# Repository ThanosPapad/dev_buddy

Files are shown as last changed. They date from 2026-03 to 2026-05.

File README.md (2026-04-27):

# DevBuddy V1
## An engineer's assistant in development.
*DevBuddy is a project under development aimed to provide engineers with an easy platform to prototype embeeded systems.*

It provides vast options in voltages to be used to supply the target board, current consumption meassurements for all channels, serial communication options and lastly a PC app to monitor and control it.
Should be able to be used for the starting point of any custom testing rig

### File breakdown
* __DevBuddy_mk1__ - _Hardware files in KiCad_.
* __Scripts__ - _Python script for the PC app_.
* __dev_buddy_v1__ - _Firmware for the RP2350 MCU / Device_.
* __Resources__ - _You can find the current PCB schematic PDF and screenshots_.

### Current capabilities
* All communication is happening over UART
* Control digital outputs commanded by the APP
* Reading digital inputs commanded by the APP
* The device is capable of reporting back to the APP measurements of Voltages and Currents of 8 channels, with the ability to switch on or off the function as well as the intervals of the reporting
* The APP looks cool as hell!
* Added support for two 8-Bit DACs for APP and Device
* Added two controllable voltage channels on PCB, firmware will have to come later
* A first version of the dispatcher is operational
* There are three channels of UART communication available to the device and APP

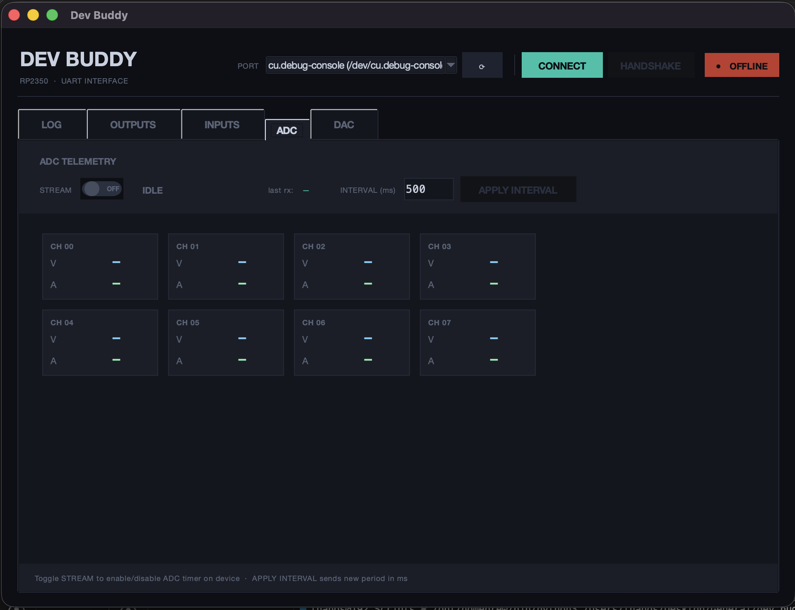
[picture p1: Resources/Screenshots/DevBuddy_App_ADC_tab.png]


There are more screenshots in the folder showcasing the app

### Things that need to be done
* Software (I2C)for the variable voltage channels control
* The ability to record sessions of measuremnts, propably saved as CSV files
* The ability to choose analog channels and view the measurements in a graph would be quite cool as well
* The schematic should progressing quicker
* Need to figure out how the external channels will work, and If external I2C is needed as well
* Add ability for actions from external interrupts, that means one or two pins accessible to the user

More updates to come soon!

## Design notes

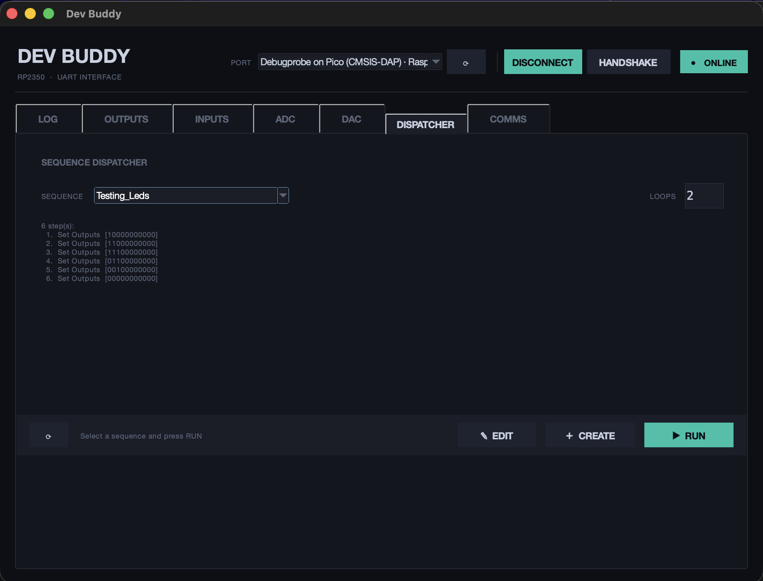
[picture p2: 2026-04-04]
Resources/Screenshots/Dispatcher.png

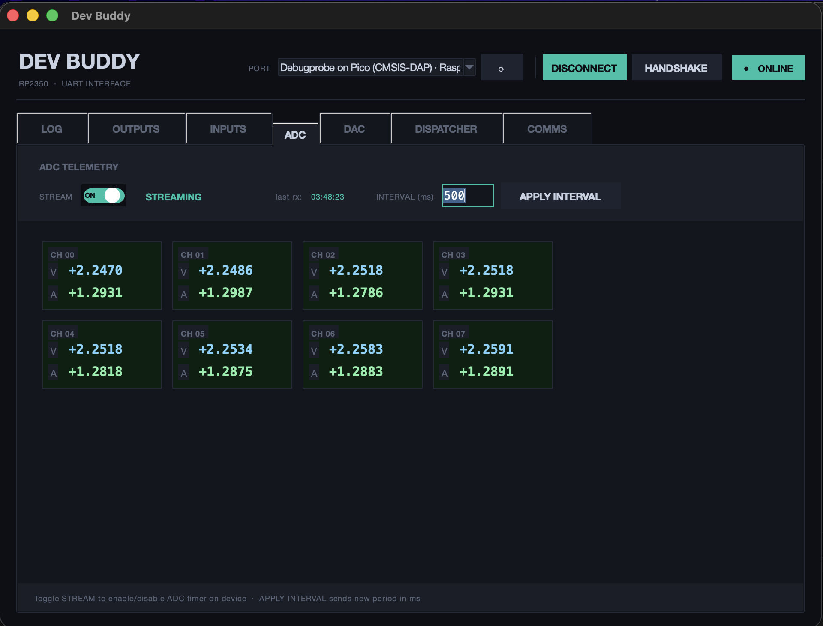
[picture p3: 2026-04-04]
Resources/Screenshots/ADC_Channels_Running.png

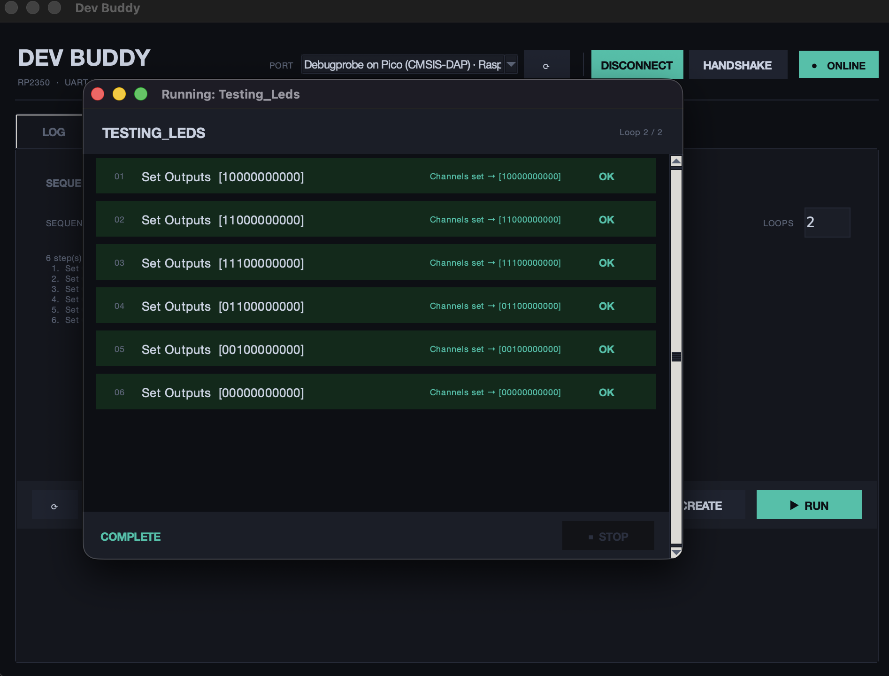
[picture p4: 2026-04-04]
Resources/Screenshots/Dispatcher_runnign.png

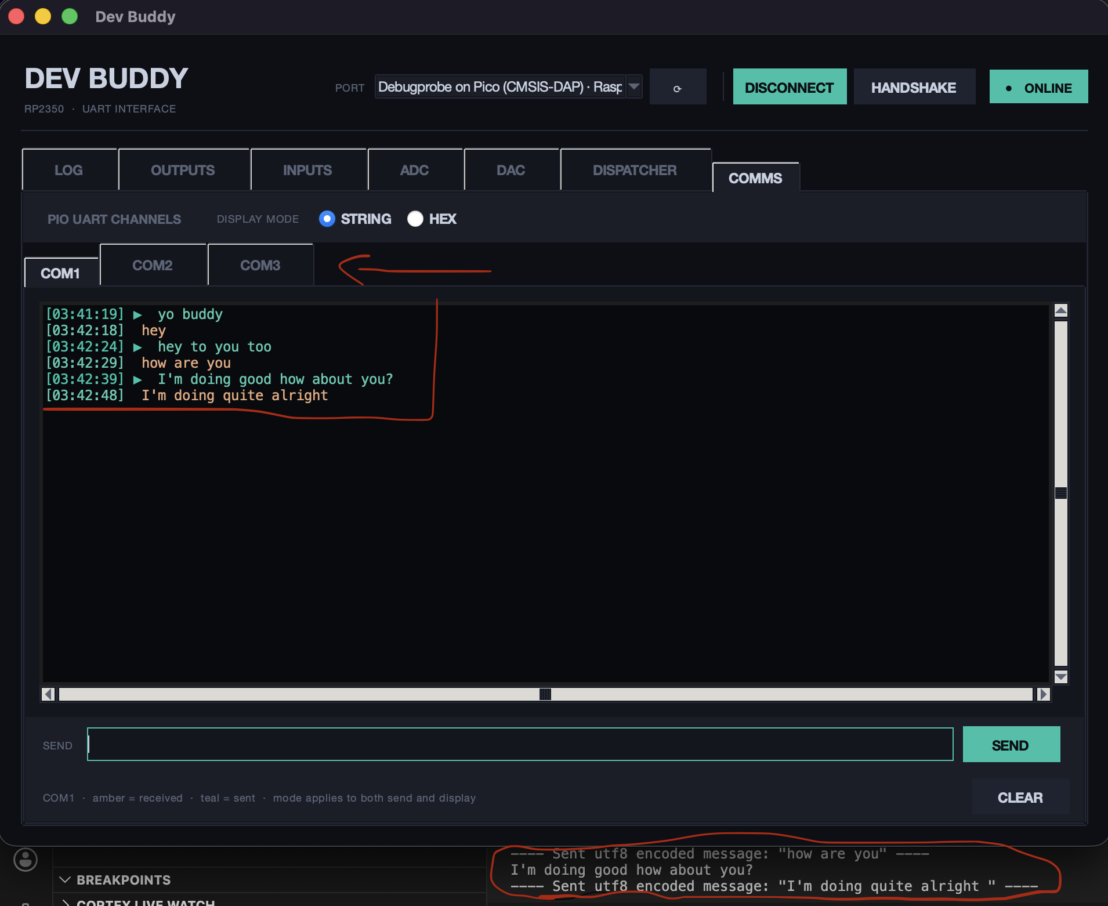
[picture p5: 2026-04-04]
Resources/Screenshots/Uart_Com1_Preview.png

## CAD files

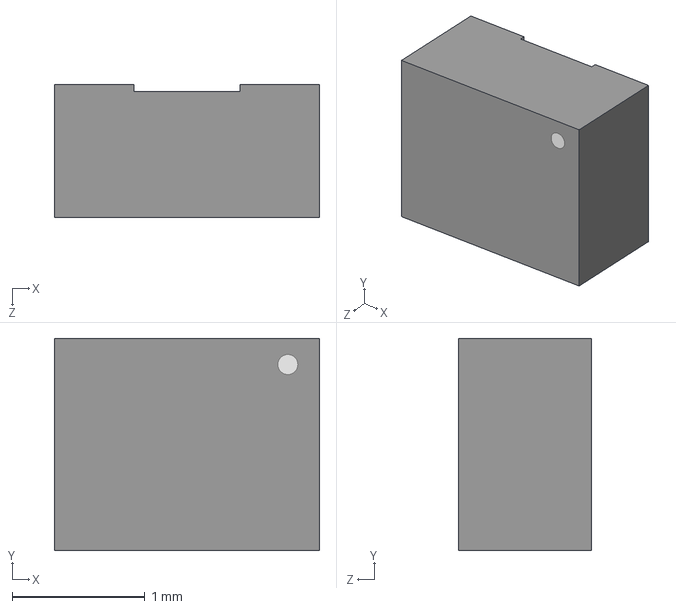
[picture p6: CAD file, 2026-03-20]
DevBuddy_mk1/AOTA-B201610S3R3-101-T/AOTA-B201610S3R3-101-T.stp
2.00 x 1.60 x 1.00 mm

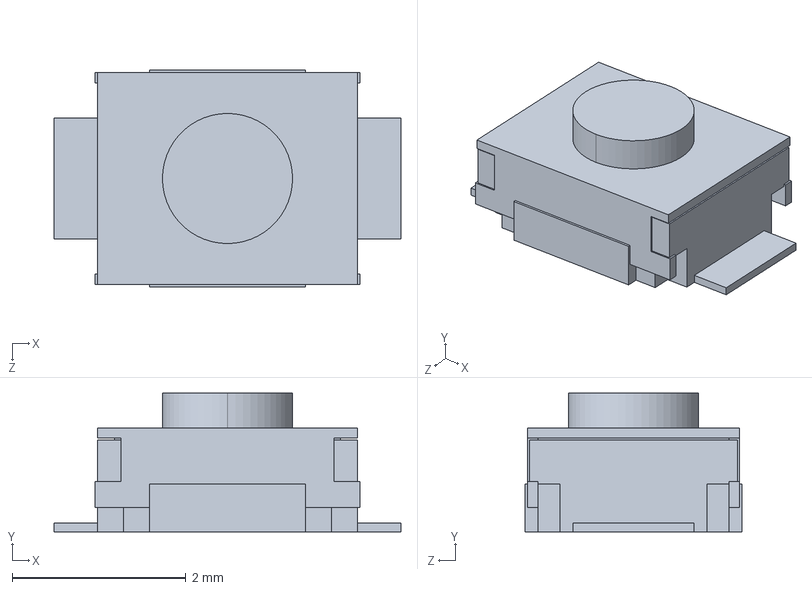
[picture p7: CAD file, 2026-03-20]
DevBuddy_mk1/Button/B3U_1000P.step
4.00 x 1.60 x 2.50 mm

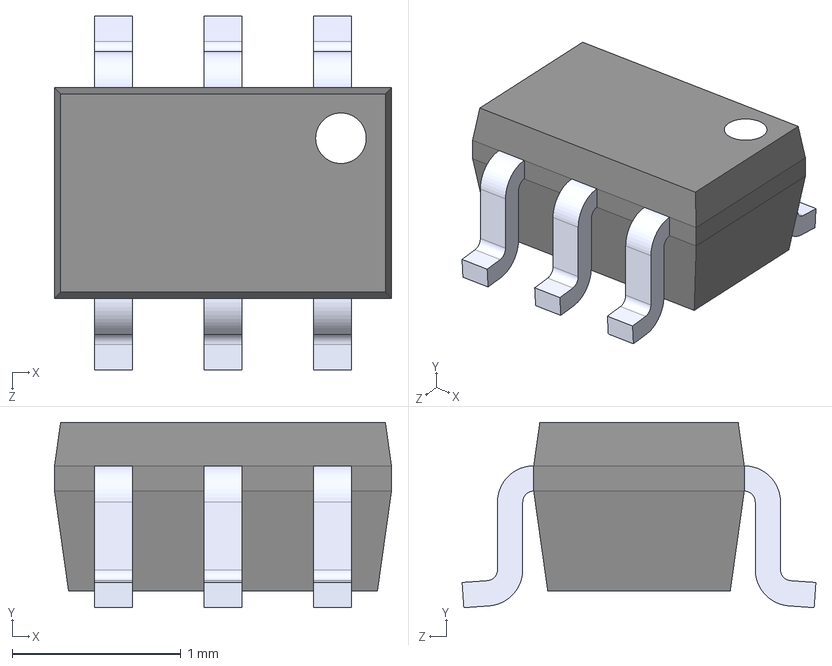
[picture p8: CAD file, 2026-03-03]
DevBuddy_mk1/INA190A2IDCKR/INA190A2IDCKR.step
2.00 x 1.10 x 2.10 mm

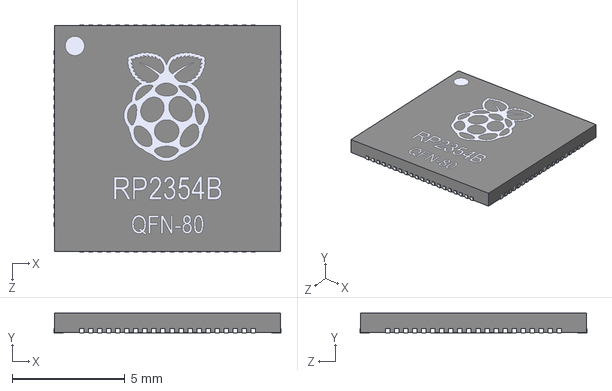
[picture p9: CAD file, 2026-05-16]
DevBuddy_mk1/RP2354B/RP2354B.step
10.1 x 0.875 x 10.1 mm

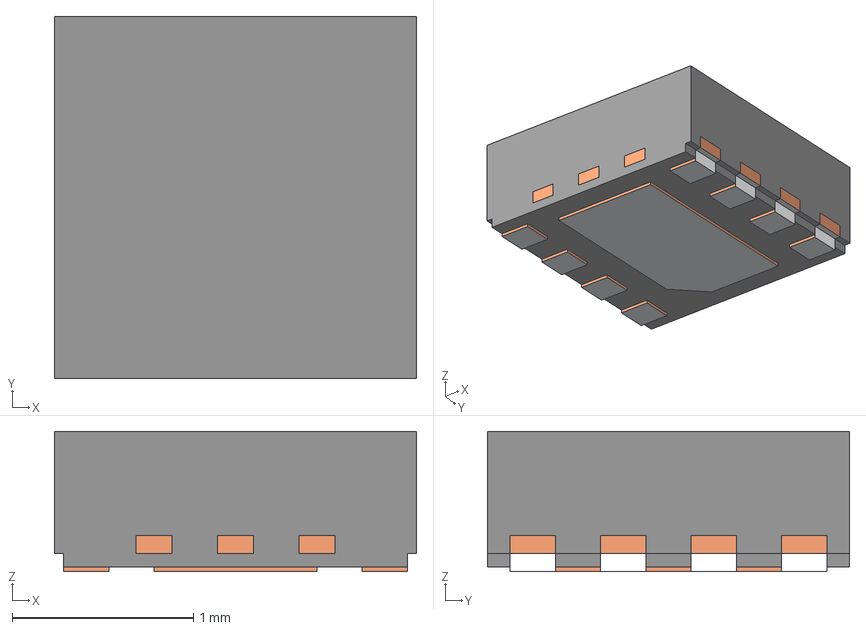
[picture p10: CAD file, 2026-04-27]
DevBuddy_mk1/TPS22965/DSG0008B.stp
2.00 x 2.00 x 0.775 mm
BODY-SON_AF0
FRAME-DSG0008B_AF0
PIN1-ID

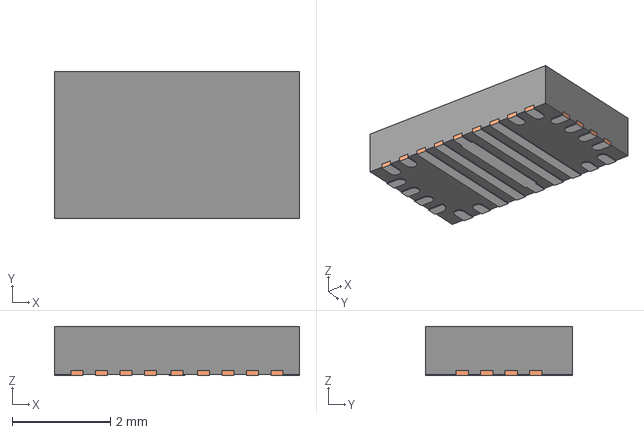
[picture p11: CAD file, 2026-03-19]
DevBuddy_mk1/ul_TPS55289RYQR/KiCADv6/RYQ0021A.stp
5.00 x 3.00 x 1.00 mm
BODY-QFN
FRAME-RYQ0021A

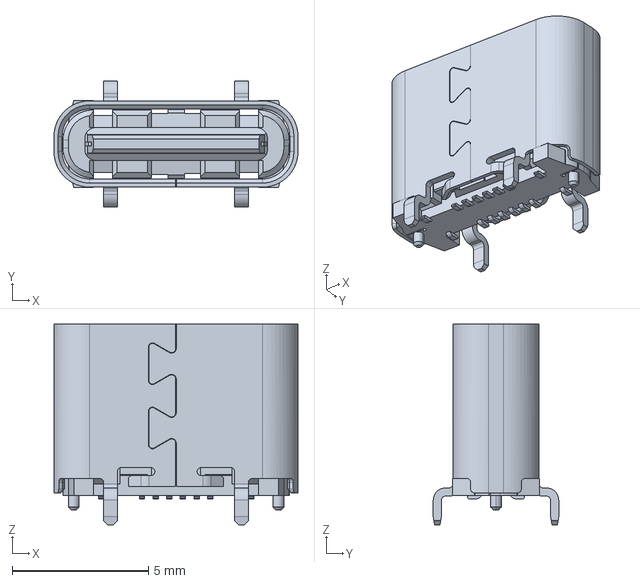
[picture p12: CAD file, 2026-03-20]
DevBuddy_mk1/USB-C-Vertical/2171820001.stp
8.94 x 4.60 x 7.35 mm

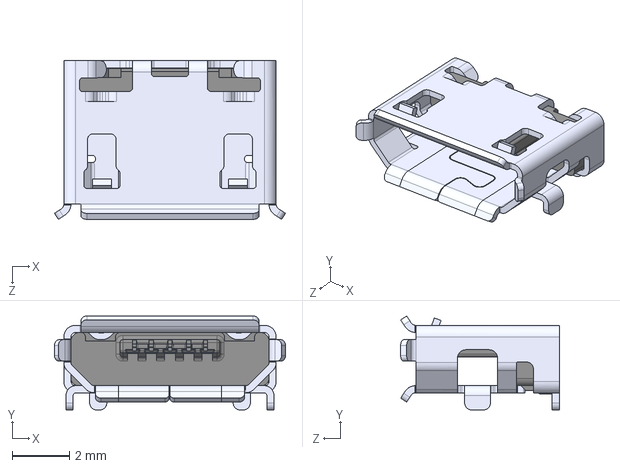
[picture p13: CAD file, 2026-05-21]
DevBuddy_mk1/usb_micro_b/10118194-0001LF.step
8.05 x 3.27 x 5.53 mm

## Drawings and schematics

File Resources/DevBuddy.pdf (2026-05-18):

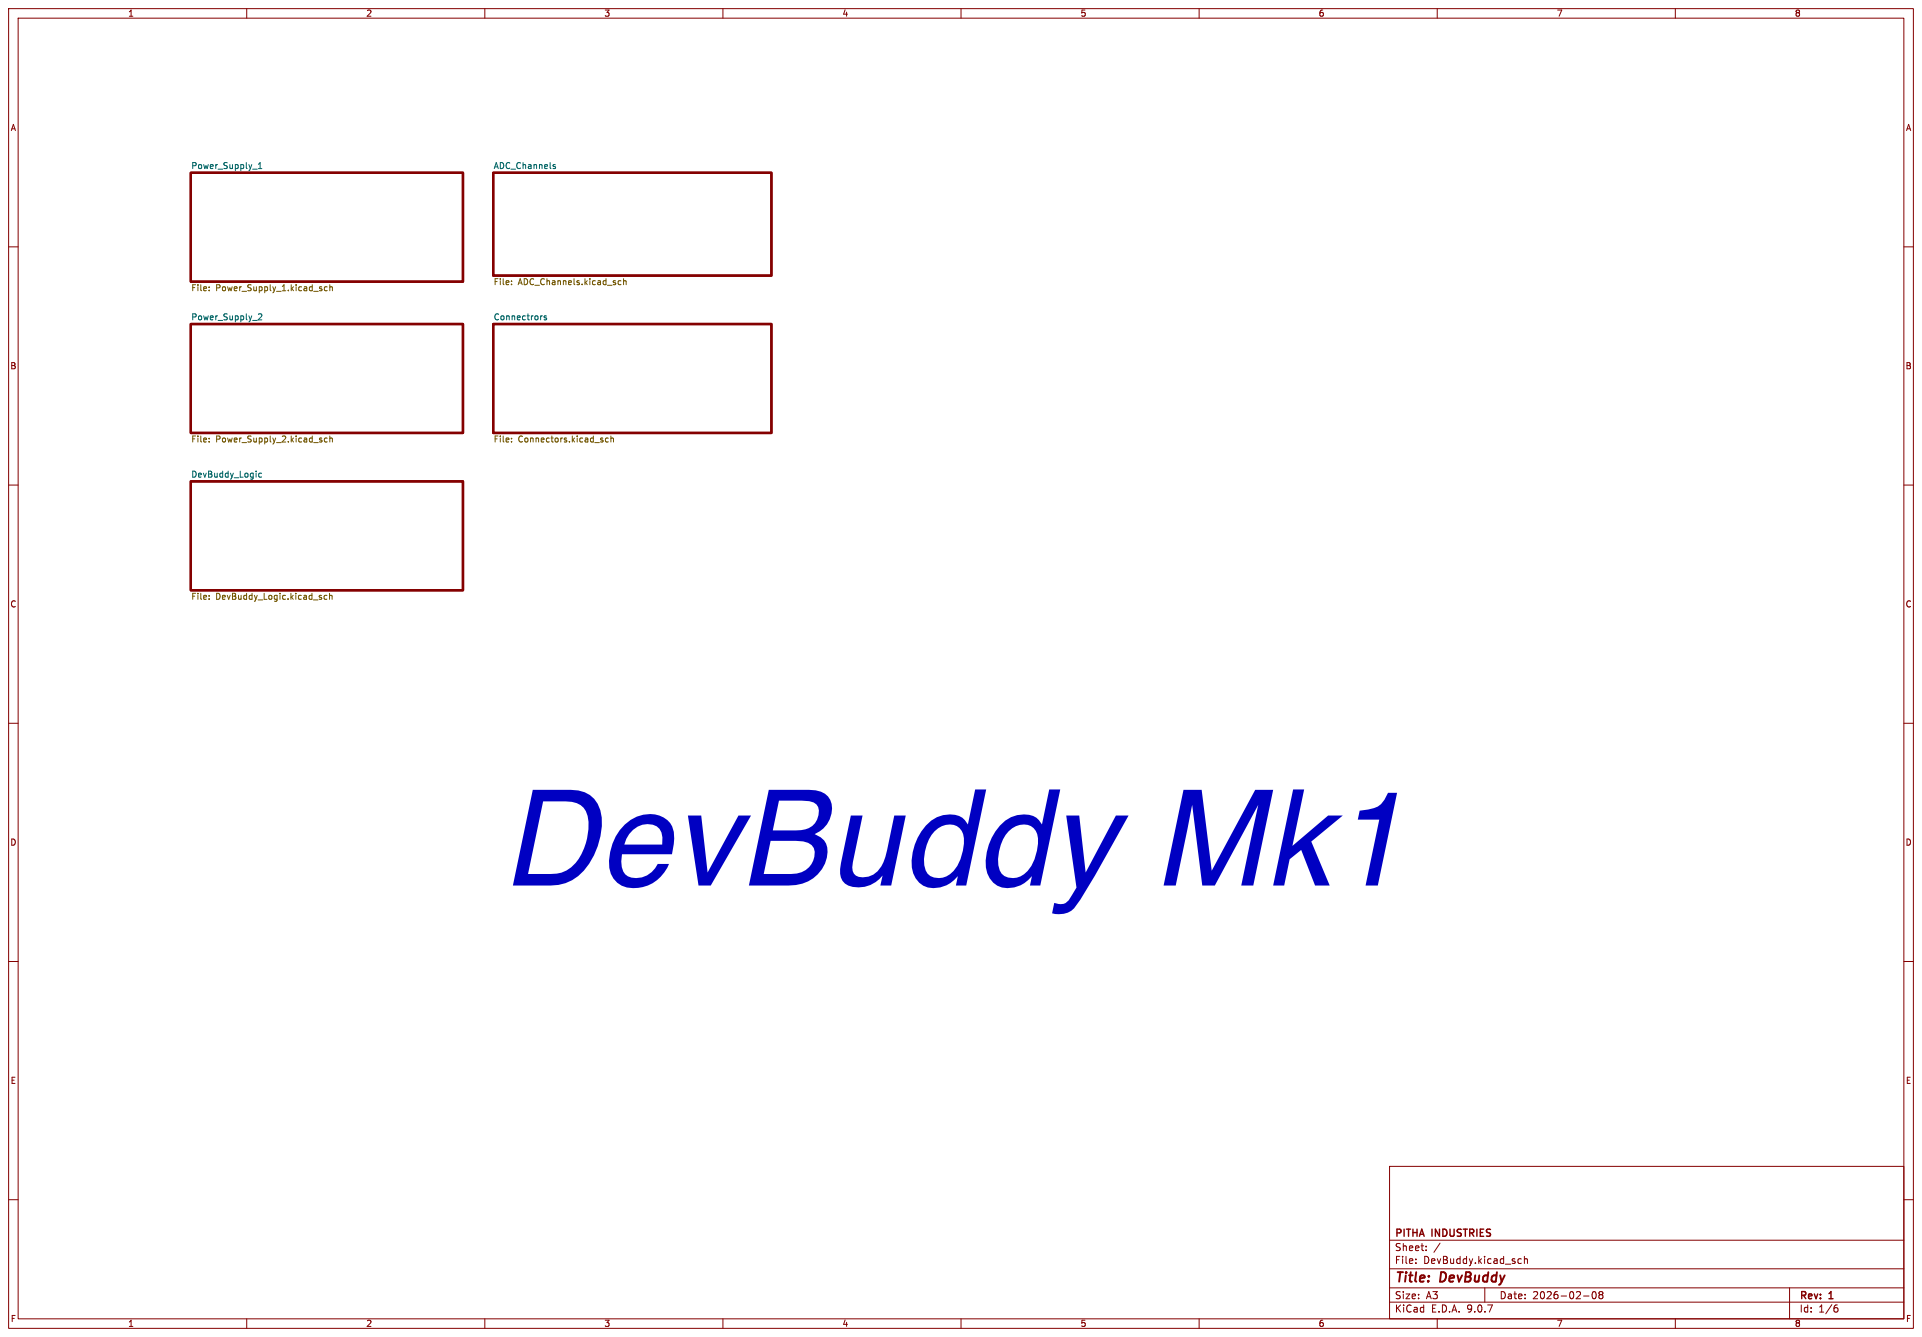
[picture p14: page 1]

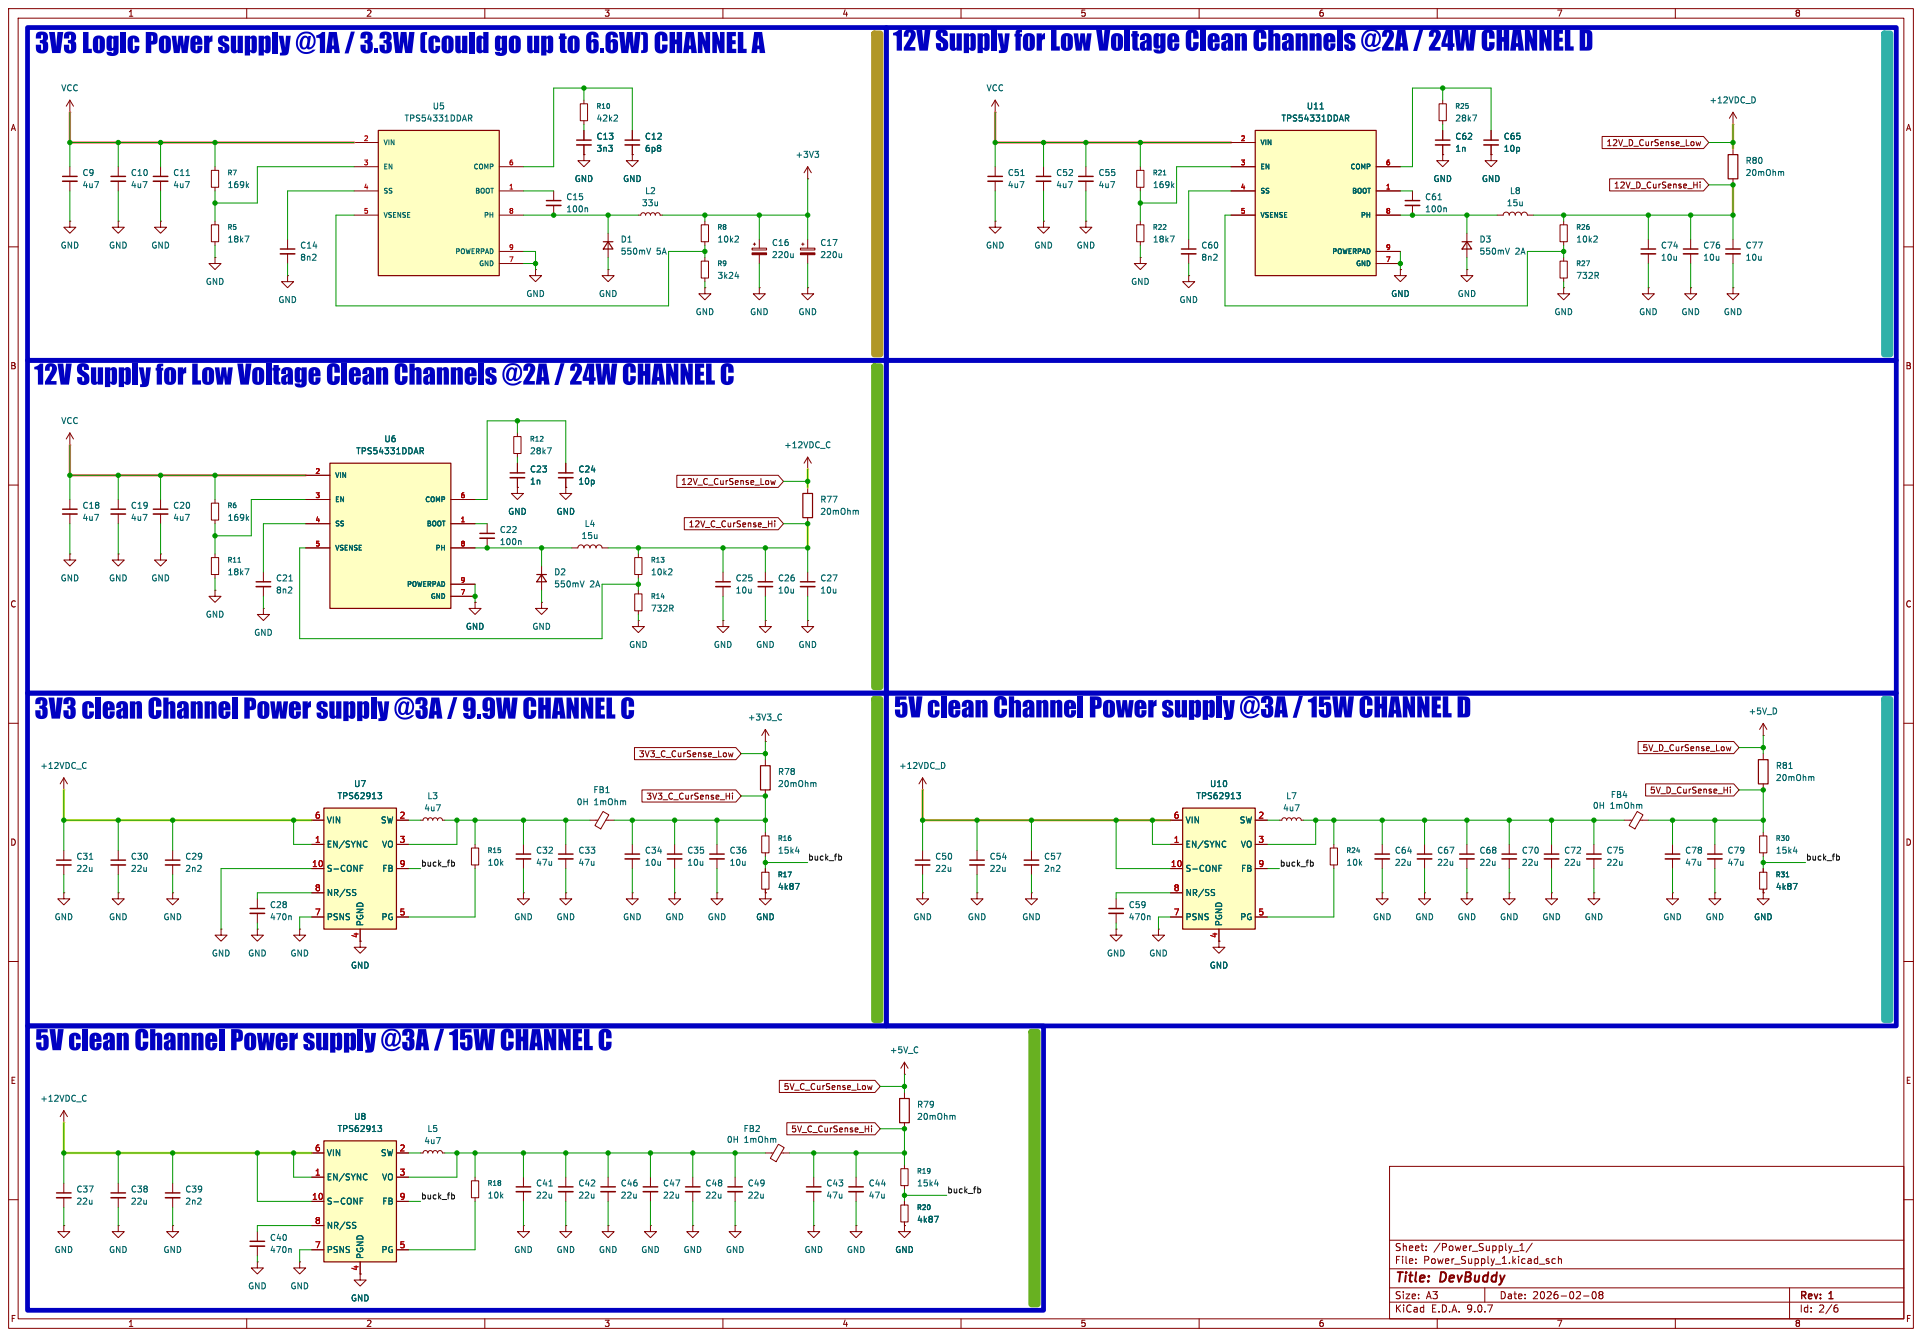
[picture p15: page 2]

4 SW 2 VO 3 FB 9 PG 5 U7 TPS62913 L3

4 SW 2 VO 3 FB 9 PG 5 U10 TPS62913 FB4

4 SW 2 VO 3 FB 9 PG 5 U8 TPS62913 VIN 6 EN/SYNC 1 S-CONF 10 NR/SS 8 PSNS 7 PGND

4 SW 2 VO 3 FB 9 PG 5 R31 4k87 GND

4 SW 2 VO 3 FB 9 PG 5 GND

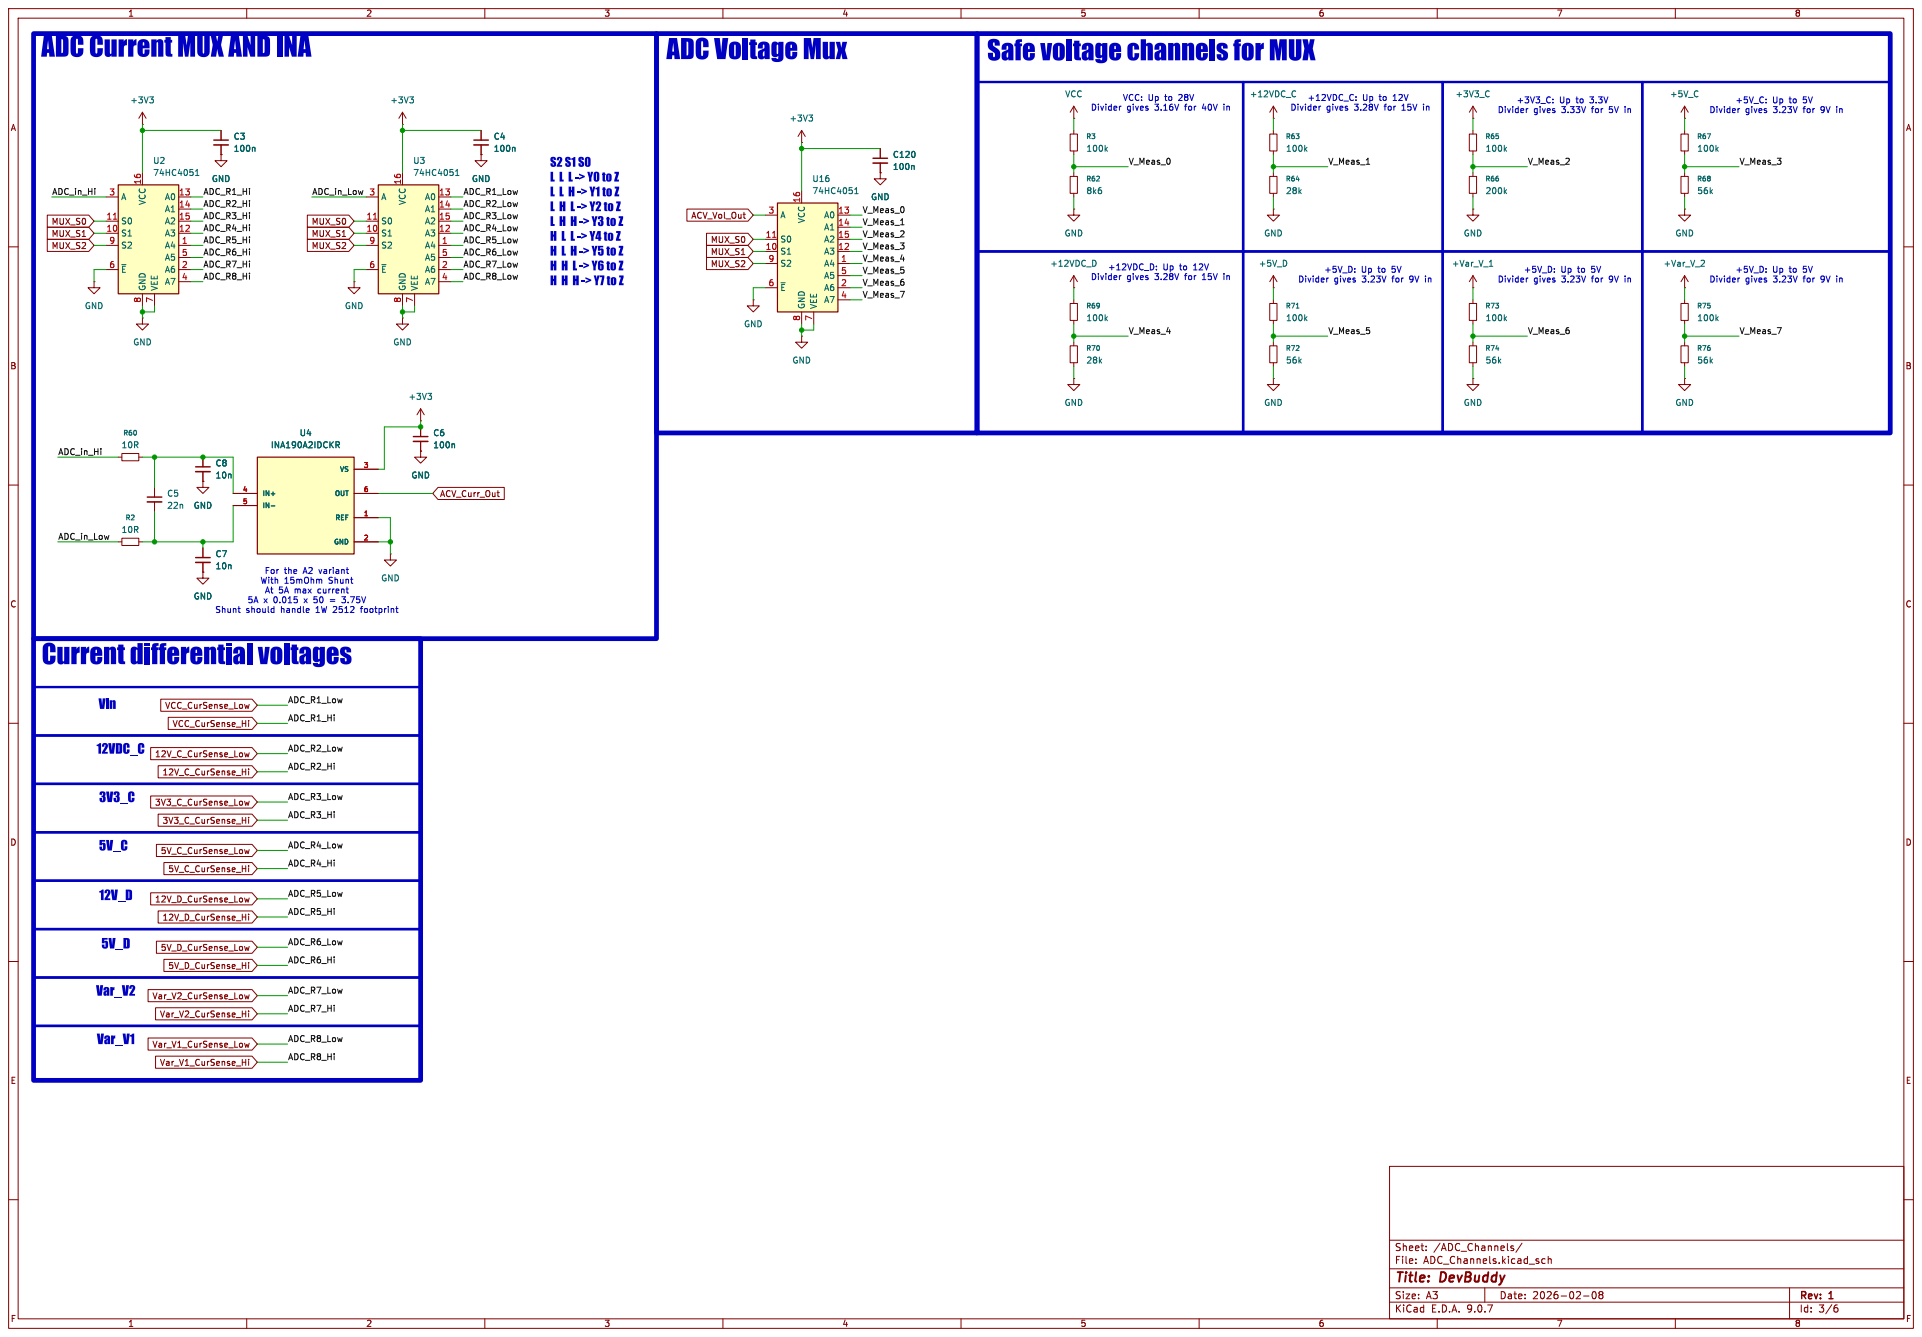
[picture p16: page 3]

+12VDC_C: Up to 12V Divider gives 3.28V for 15V in 3V3_C

VCC: Up to 28V Divider gives 3.16V for 40V in S2S1S0

+5V_C: Up to 5V Divider gives 3.23V for 9V in

+5V_D: Up to 5V Divider gives 3.23V for 9V in GND

+5V_D: Up to 5V Divider gives 3.23V for 9V in Currentdifferential voltages

For the A2 variant With 15mOhm Shunt At 5A max current 5A x 0.015 x 50 = 3.75V

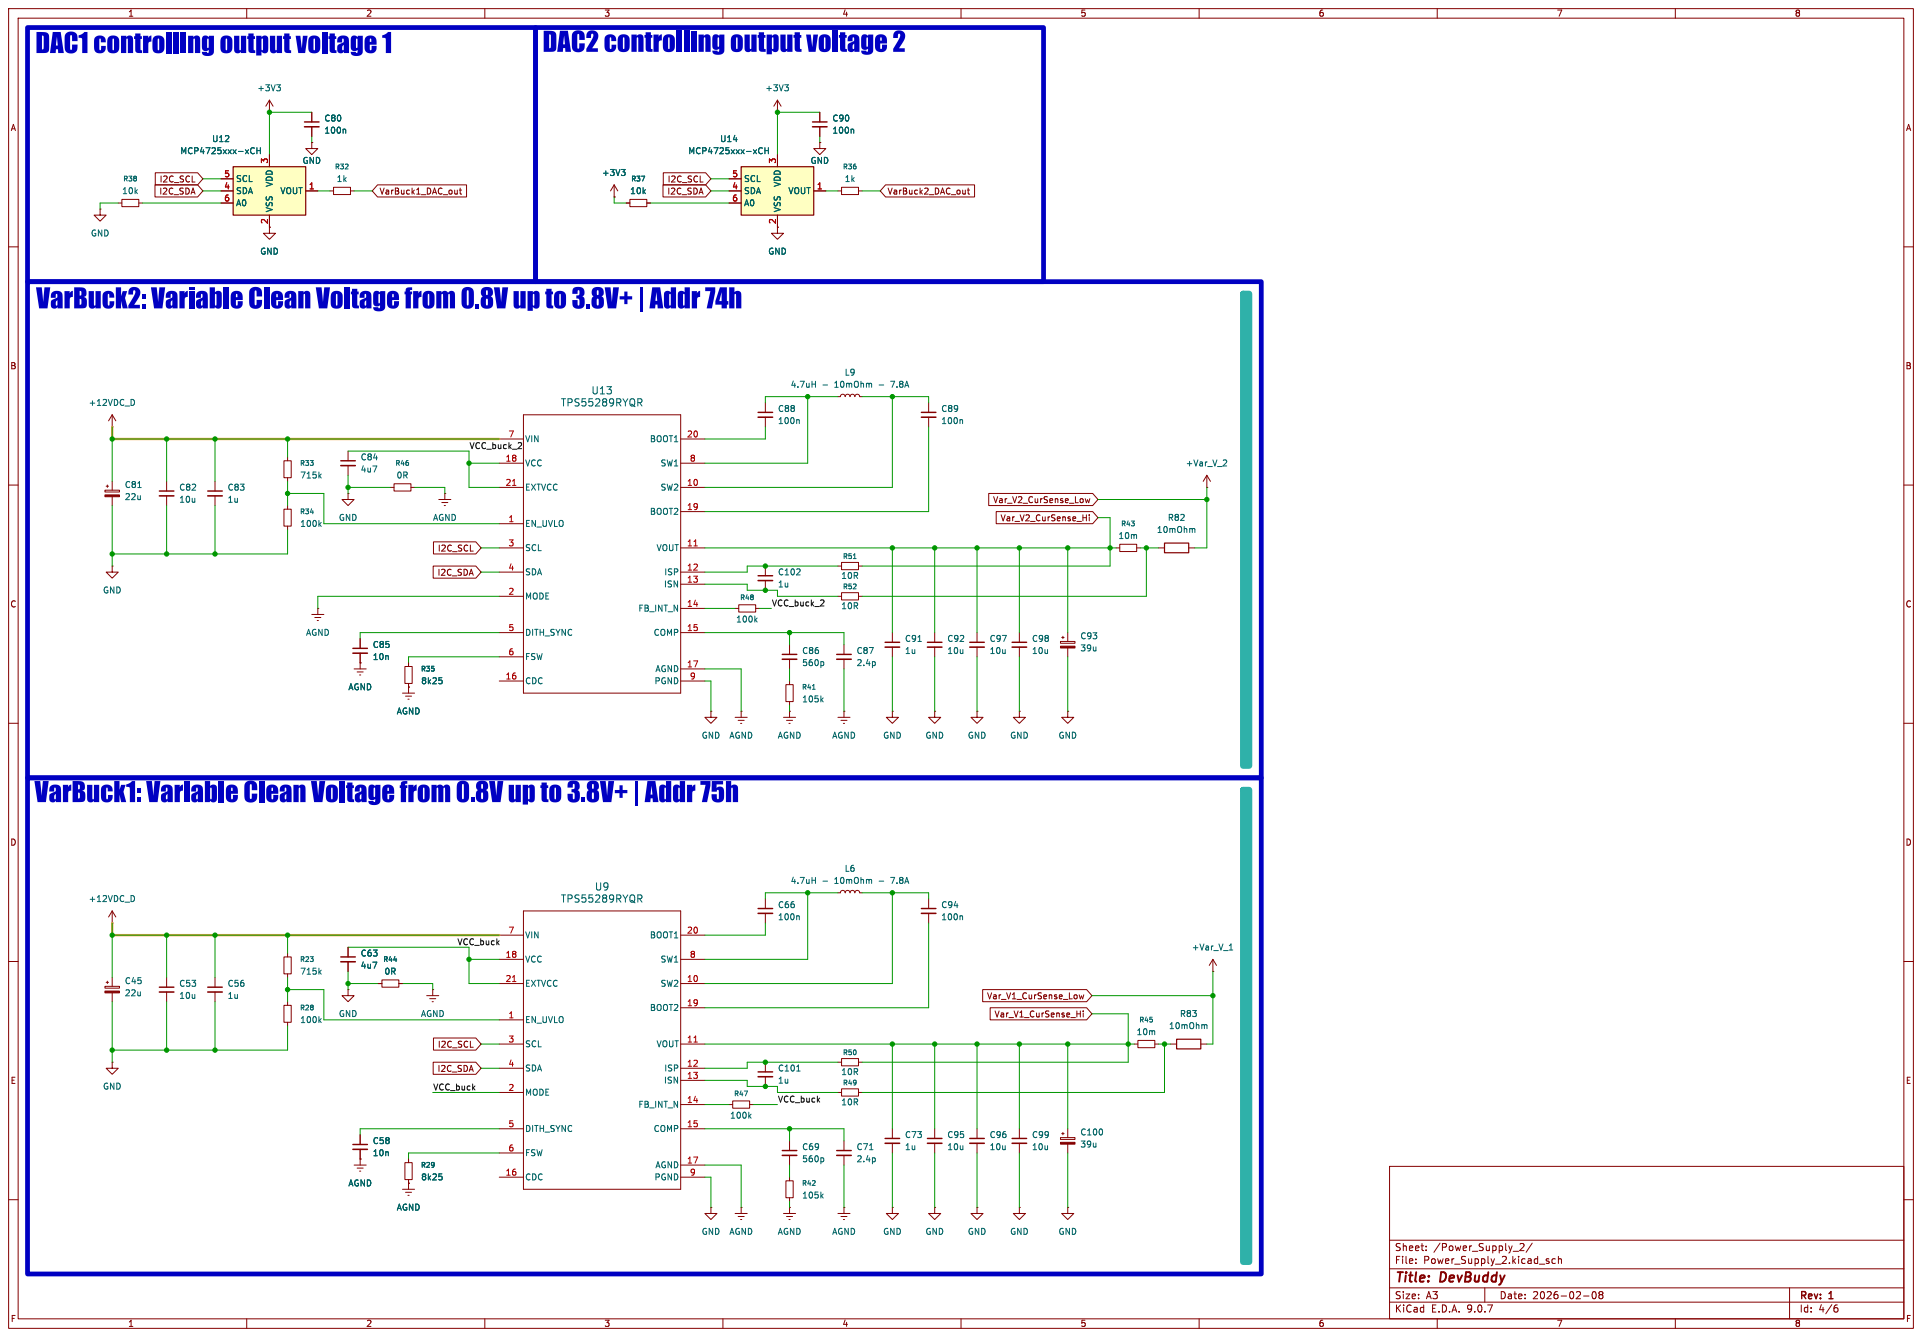
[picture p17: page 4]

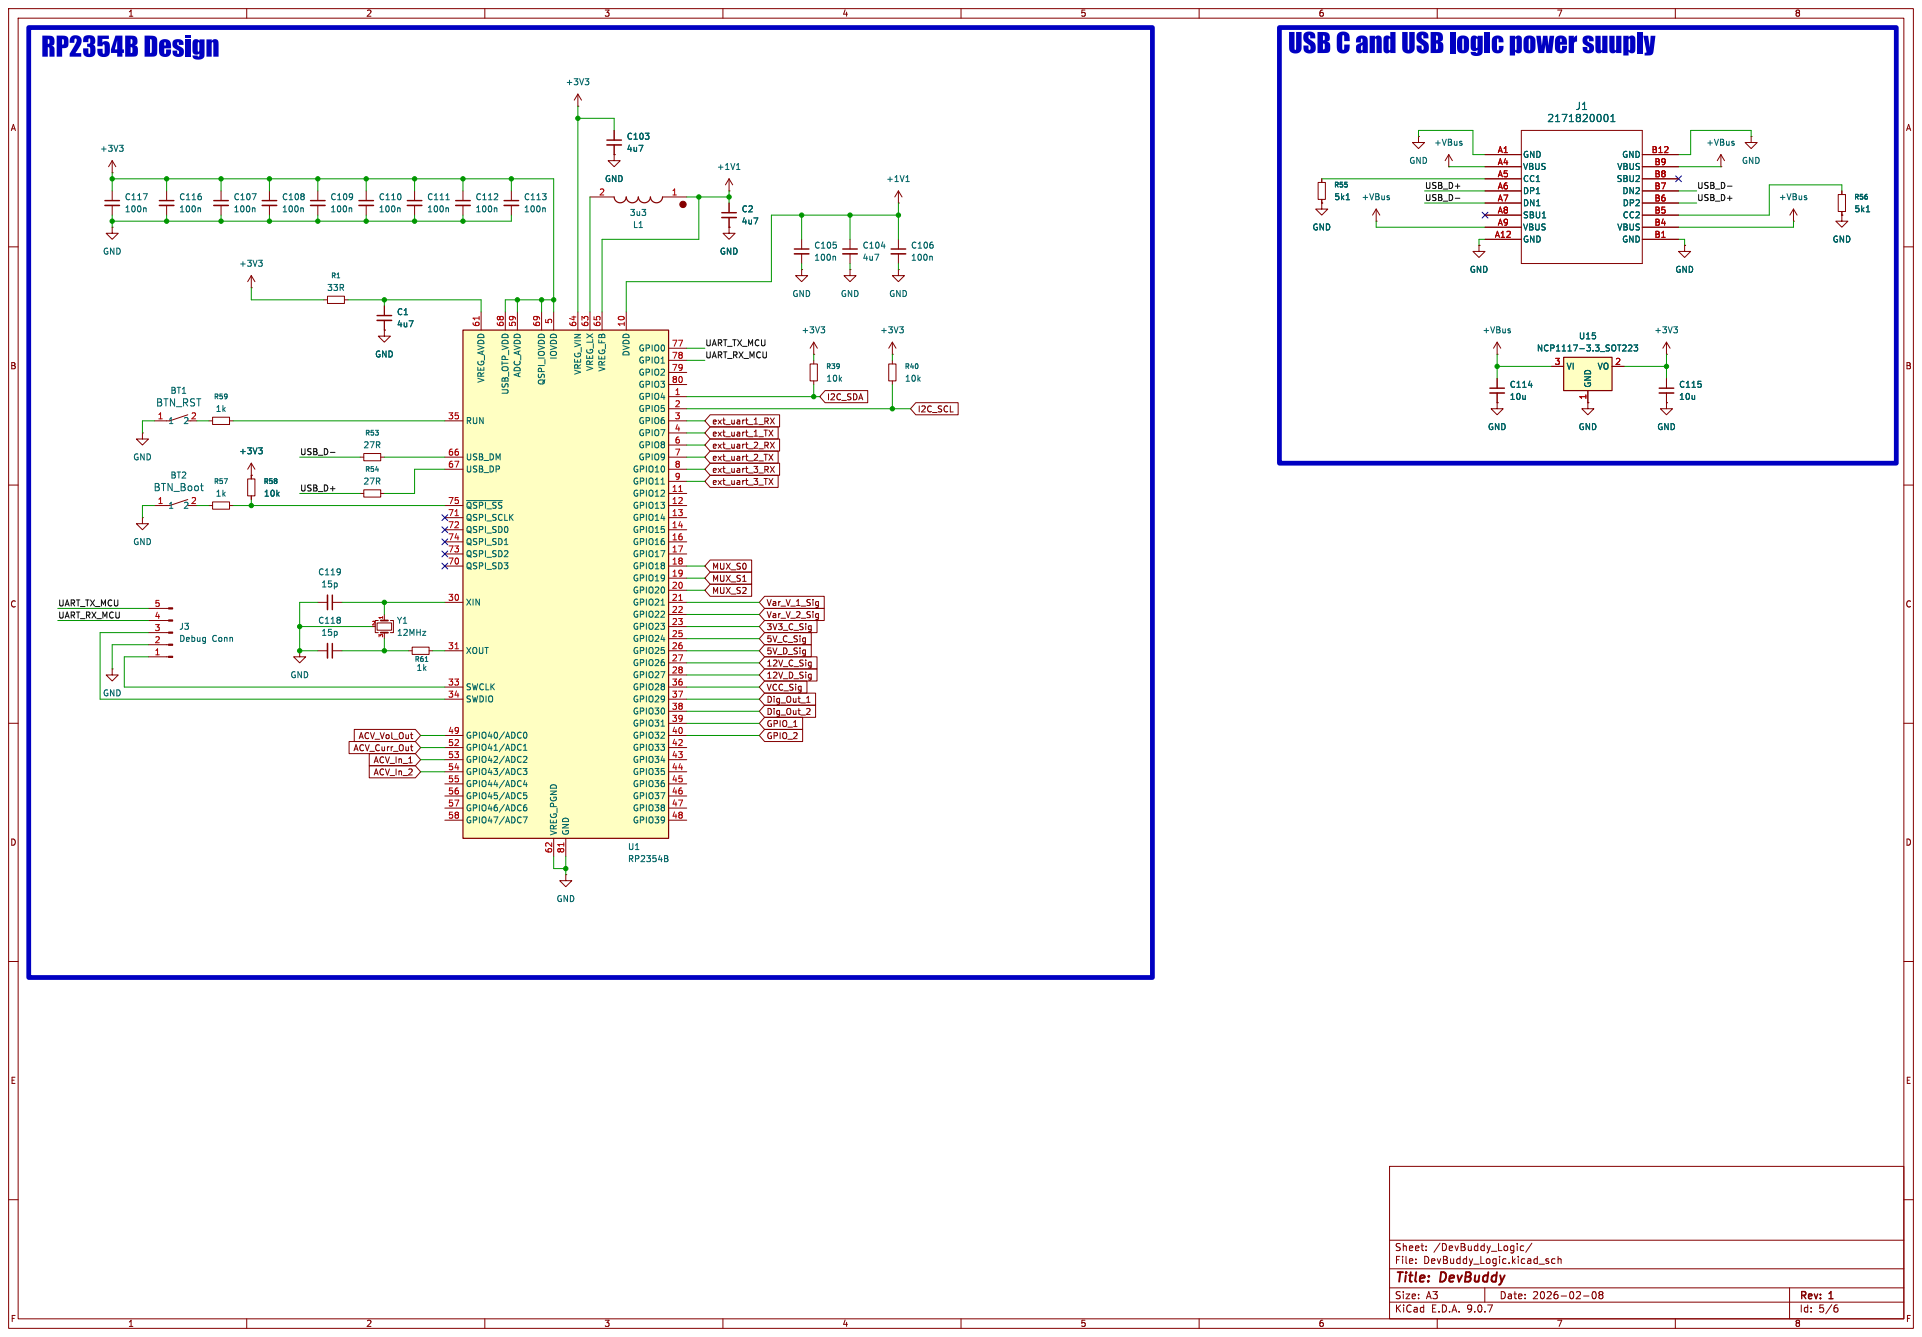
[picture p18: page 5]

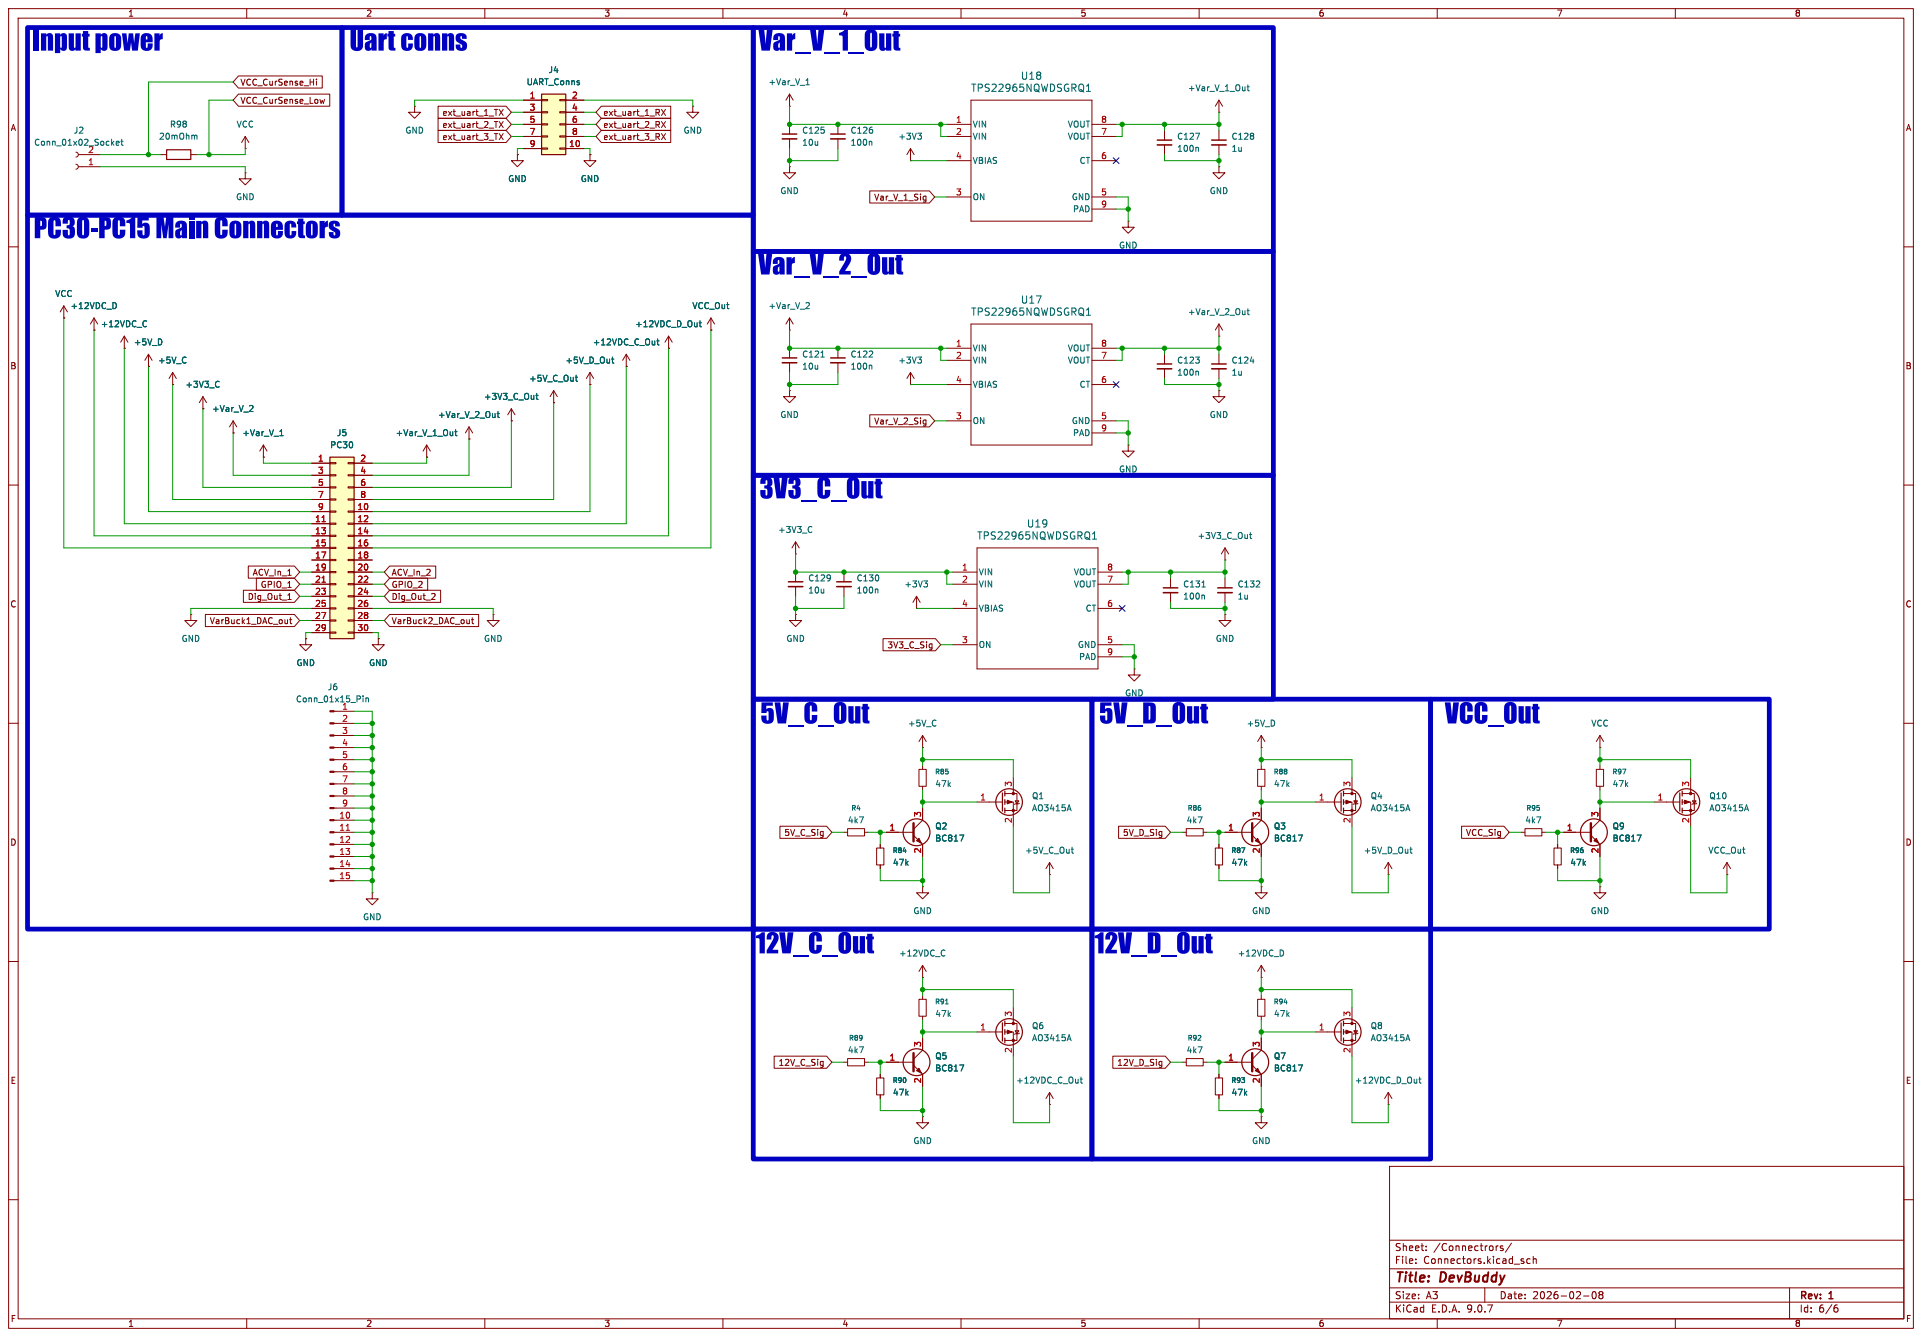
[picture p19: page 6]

File: Connectors.kicad_sch Sheet: /Connectrors/
Id: 6/6 Title: DevBuddy

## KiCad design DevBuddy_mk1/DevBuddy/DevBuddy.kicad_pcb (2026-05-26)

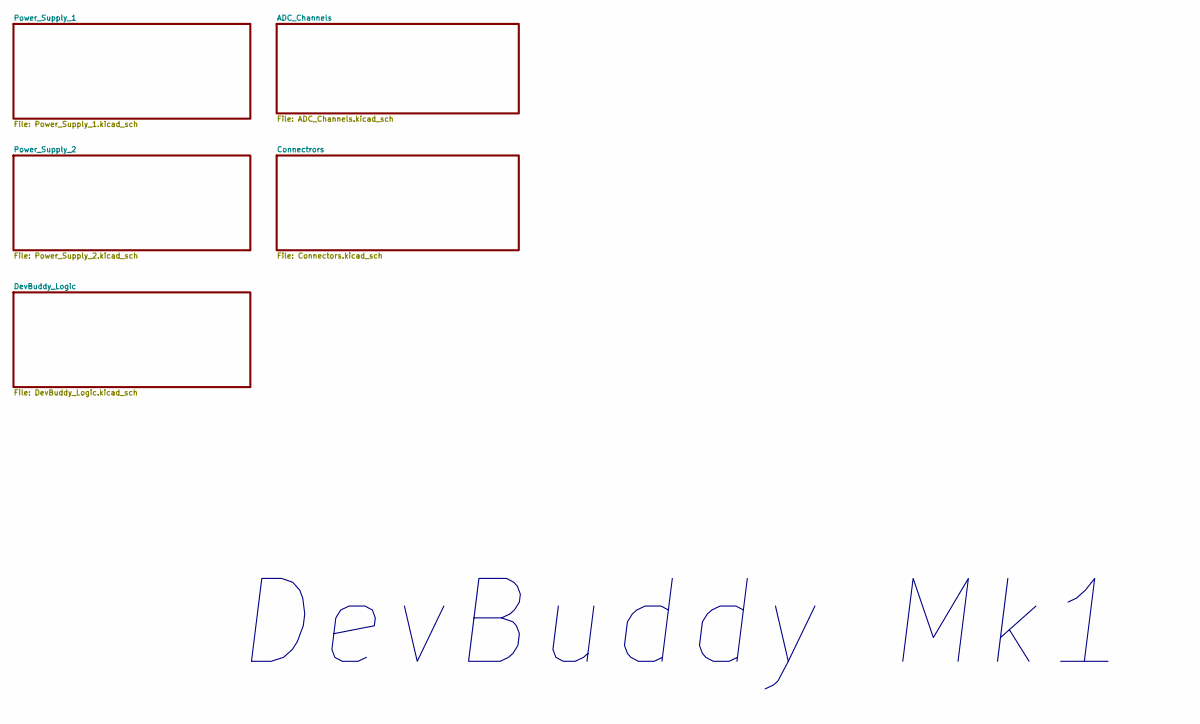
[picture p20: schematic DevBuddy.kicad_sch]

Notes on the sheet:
DevBuddy Mk1

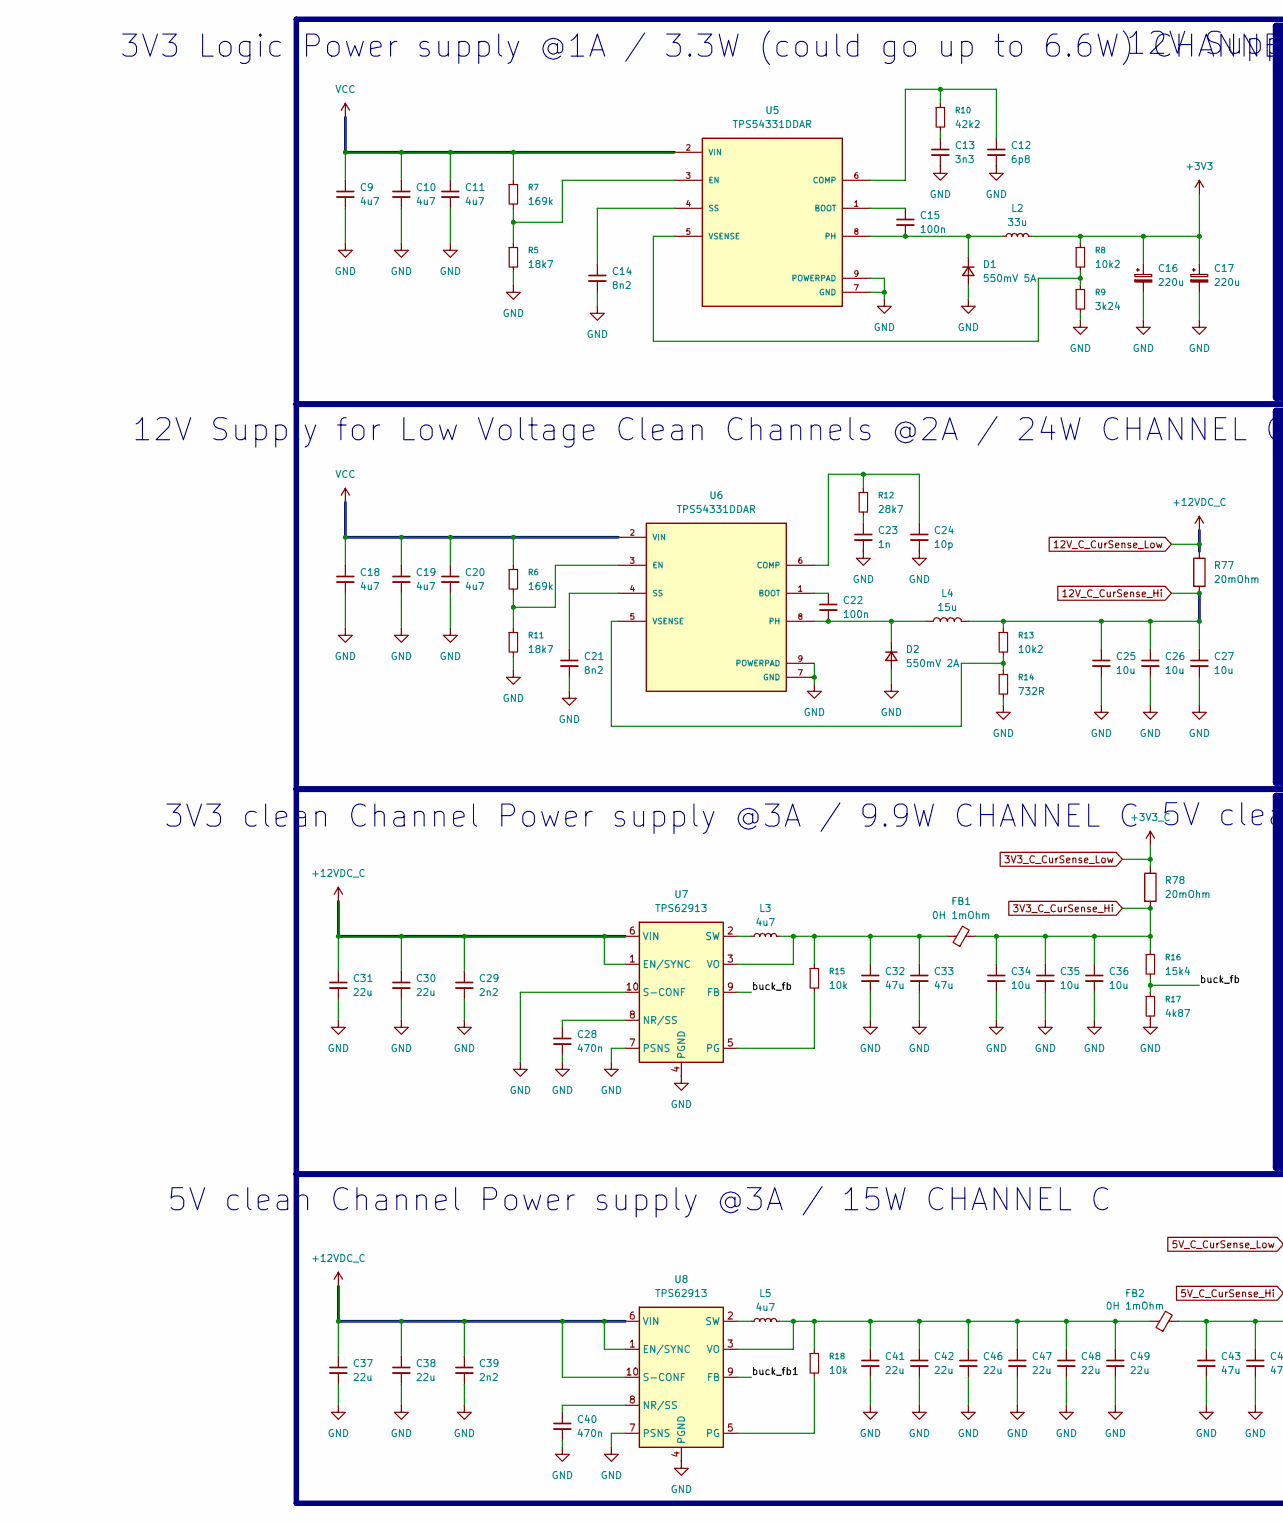
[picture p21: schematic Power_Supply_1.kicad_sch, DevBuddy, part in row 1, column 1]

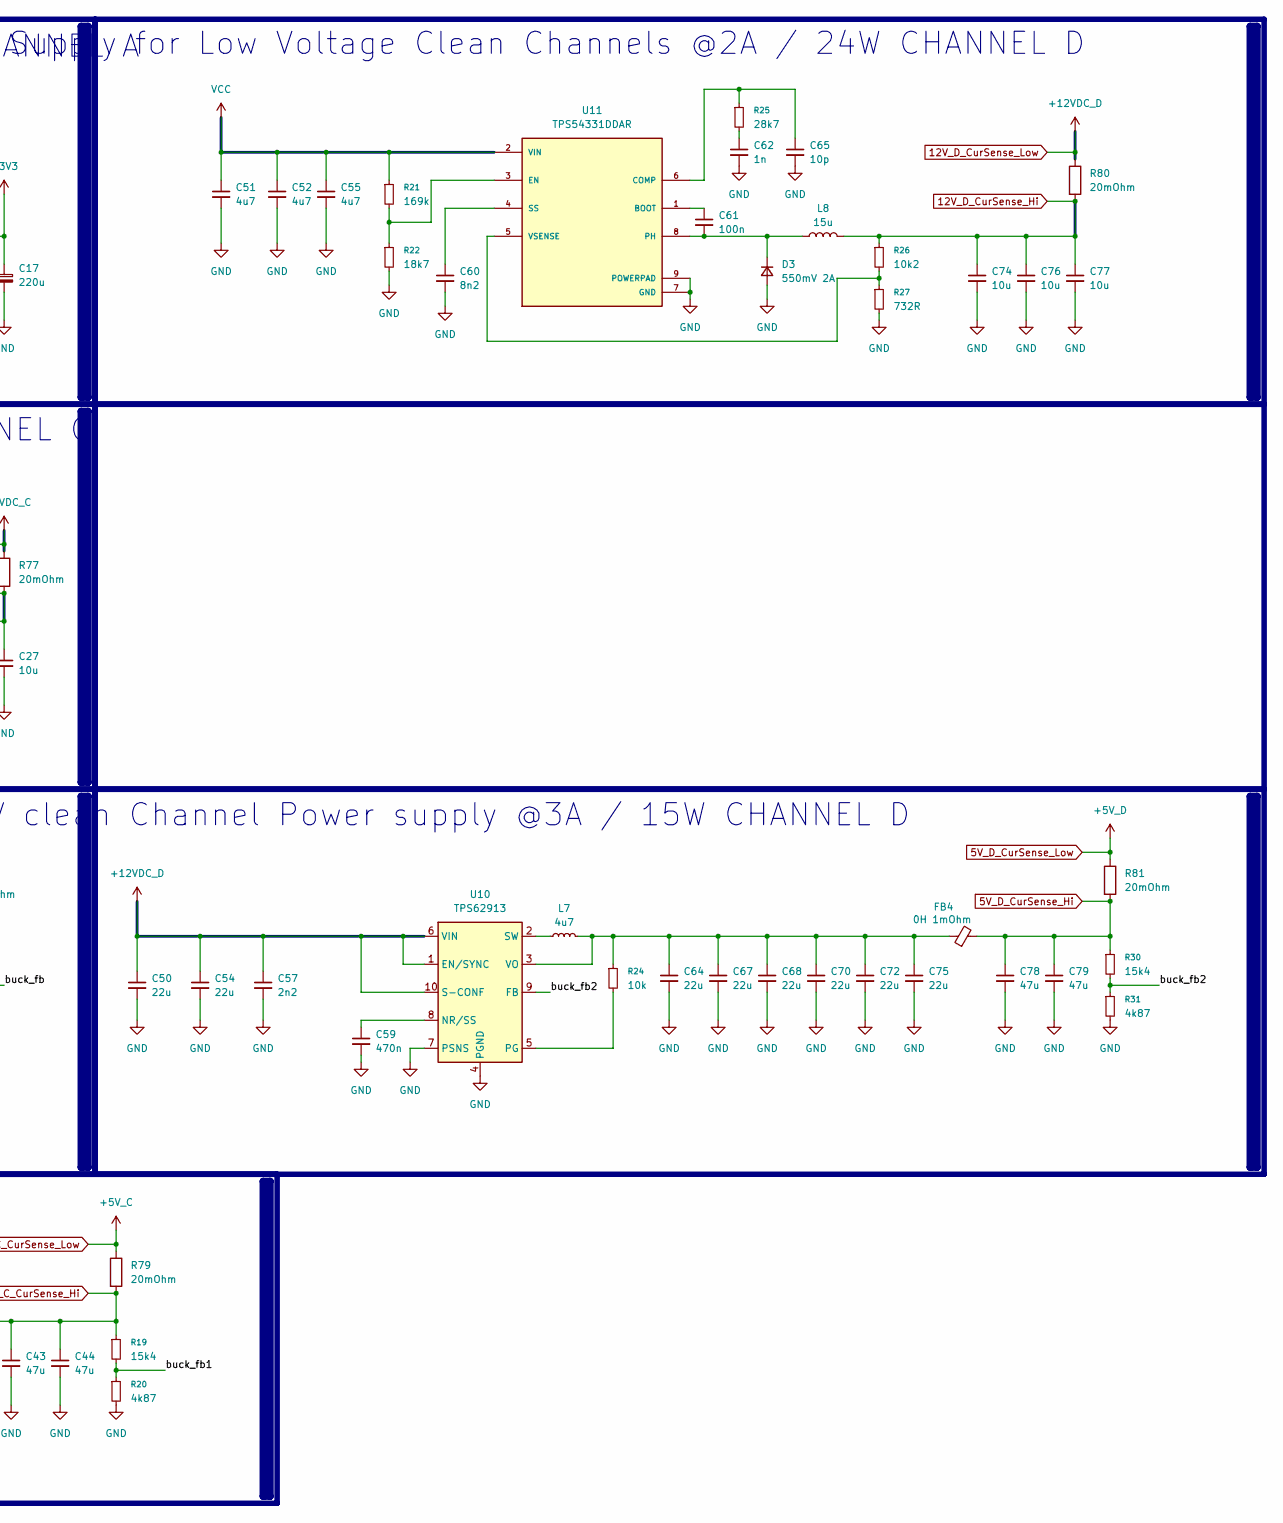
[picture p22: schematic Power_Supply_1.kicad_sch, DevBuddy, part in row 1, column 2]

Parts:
C9, C10, C11, C18, C19, C20, C51, C52, C55: 4u7; C_1210_3225Metric
C12: 6p8; C_0402_1005Metric
C13: 3n3; C_0402_1005Metric
C14, C21, C60: 8n2; C_0402_1005Metric
C15, C22, C61: 100n; C_0805_2012Metric
C16, C17: 220u; CP_Elec_6.3x5.4
C23, C62: 1n; C_0402_1005Metric
C24, C65: 10p; C_0402_1005Metric
C25, C26, C27, C74, C76, C77: 10u; C_1210_3225Metric
C28, C40, C59: 470n; C_0402_1005Metric
C29, C39, C57: 2n2; C_0402_1005Metric
C30, C31, C37, C38, C41, C42, C46, C47, C48, C49, C50, C54, C64, C67, C68, C70, C72, C75: 22u; C_0805_2012Metric
C32, C33, C43, C44, C78, C79: 47u; C_0805_2012Metric
C34, C35, C36: 10u; C_0805_2012Metric
D1: 550mV 5A; D_SMC
D2, D3: 550mV 2A; D_SMC
FB1, FB2, FB4: 0H 1mOhm; Fuse_1206_3216Metric
L2: 33u; L_Coilcraft_MSS1210-XXX
L3, L5, L7: 4u7; L_Coilcraft_XAL6060-XXX
L4, L8: 15u; L_Bourns_SRR1260
R5, R11, R22: 18k7; R_0402_1005Metric
R6, R7, R21: 169k; R_0402_1005Metric
R8, R13, R26: 10k2; R_0402_1005Metric
R9: 3k24; R_0402_1005Metric
R10: 42k2; R_0402_1005Metric
R12, R25: 28k7; R_0402_1005Metric
R14, R27: 732R; R_0402_1005Metric
R15, R18, R24: 10k; R_0402_1005Metric
R16, R19, R30: 15k4; R_0402_1005Metric
R17, R20, R31: 4k87; R_0402_1005Metric
R77, R78, R79, R80, R81: 20mOhm; R_1210_3225Metric
U5, U6, U11: TPS54331DDAR; CONV_TPS54331DDAR; PARTREV F
U7, U8, U10: TPS62913; Texas_RPU0010A_VQFN-HR-10_2x2mm_P0.5mm

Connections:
3V3_C_CurSense_Hi: C34.1, C35.1, C36.1, FB1.2, R16.1, R78.2; also elsewhere on the board
3V3_C_CurSense_Low: R78.1; also elsewhere on the board
5V_C_CurSense_Hi: C43.1, C44.1, FB2.2, R19.1, R79.2; also elsewhere on the board
5V_C_CurSense_Low: R79.1; also elsewhere on the board
5V_D_CurSense_Hi: C78.1, C79.1, FB4.2, R30.1, R81.2; also elsewhere on the board
5V_D_CurSense_Low: R81.1; also elsewhere on the board
12V_C_CurSense_Hi: C25.1, C26.1, C27.1, L4.2, R13.1, R77.2; also elsewhere on the board
12V_C_CurSense_Low: C29.1, C30.1, C31.1, C37.1, C38.1, C39.1, R77.1, U7.1 (EN/SYNC), U7.6 (VIN), U8.1 (EN/SYNC), U8.6 (VIN), U8.10 (S-CONF); also elsewhere on the board
12V_D_CurSense_Hi: C74.1, C76.1, C77.1, L8.2, R26.1, R80.2; also elsewhere on the board
12V_D_CurSense_Low: C50.1, C54.1, C57.1, R80.1, U10.1 (EN/SYNC), U10.6 (VIN), U10.10 (S-CONF); also elsewhere on the board
+3V3: C16.1, C17.1, L2.2, R8.1; also elsewhere on the board
/Power_Supply_1/buck_fb: R16.2, R17.1, U7.9 (FB)
/Power_Supply_1/buck_fb1: R19.2, R20.1, U8.9 (FB)
/Power_Supply_1/buck_fb2: R30.2, R31.1, U10.9 (FB)
GND: C9.2, C10.2, C11.2, C12.2, C13.2, C14.2, C16.2, C17.2, C18.2, C19.2, C20.2, C21.2, C23.2, C24.2, C25.2, C26.2, C27.2, C28.2, C29.2, C30.2, C31.2, C32.2, C33.2, C34.2, C35.2, C36.2, C37.2, C38.2, C39.2, C40.2, C41.2, C42.2, C43.2, C44.2, C46.2, C47.2, C48.2, C49.2, C50.2, C51.2, C52.2, C54.2, C55.2, C57.2, C59.2, C60.2, C62.2, C64.2, C65.2, C67.2, C68.2, C70.2, C72.2, C74.2, C75.2, C76.2, C77.2, C78.2, C79.2, D1.2 (A), D2.2 (A), D3.2 (A), R5.2, R9.2, R11.2, R14.2, R17.2, R20.2, R22.2, R27.2, R31.2, U5.7 (GND), U5.9 (POWERPAD), U6.7 (GND), U6.9 (POWERPAD), U7.4 (PGND), U7.7 (PSNS), U7.10 (S-CONF), U8.4 (PGND), U8.7 (PSNS), U10.4 (PGND), U10.7 (PSNS), U11.7 (GND), U11.9 (POWERPAD); also elsewhere on the board
unnamed: C13.1, R10.2
unnamed: C23.1, R12.2
unnamed: C62.1, R25.2
unnamed: C15.2, D1.1 (K), L2.1, U5.8 (PH)
unnamed: C22.2, D2.1 (K), L4.1, U6.8 (PH)
unnamed: C61.2, D3.1 (K), L8.1, U11.8 (PH)
unnamed: C15.1, U5.1 (BOOT)
unnamed: C12.1, R10.1, U5.6 (COMP)
unnamed: R5.1, R7.2, U5.3 (EN)
unnamed: C14.1, U5.4 (SS)
unnamed: R8.2, R9.1, U5.5 (VSENSE)
unnamed: C22.1, U6.1 (BOOT)
unnamed: C24.1, R12.1, U6.6 (COMP)
unnamed: R6.2, R11.1, U6.3 (EN)
unnamed: C21.1, U6.4 (SS)
unnamed: R13.2, R14.1, U6.5 (VSENSE)
unnamed: C28.1, U7.8 (NR/SS)
unnamed: R15.2, U7.5 (PG)
unnamed: L3.1, U7.2 (SW)
unnamed: C32.1, C33.1, FB1.1, L3.2, R15.1, U7.3 (VO)
unnamed: C40.1, U8.8 (NR/SS)
unnamed: R18.2, U8.5 (PG)
unnamed: L5.1, U8.2 (SW)
unnamed: C41.1, C42.1, C46.1, C47.1, C48.1, C49.1, FB2.1, L5.2, R18.1, U8.3 (VO)
unnamed: C59.1, U10.8 (NR/SS)
unnamed: R24.2, U10.5 (PG)
unnamed: L7.1, U10.2 (SW)
unnamed: C64.1, C67.1, C68.1, C70.1, C72.1, C75.1, FB4.1, L7.2, R24.1, U10.3 (VO)
unnamed: C61.1, U11.1 (BOOT)
unnamed: C65.1, R25.1, U11.6 (COMP)
unnamed: R21.2, R22.1, U11.3 (EN)
unnamed: C60.1, U11.4 (SS)
unnamed: R26.2, R27.1, U11.5 (VSENSE)
VCC_CurSense_Low: C9.1, C10.1, C11.1, C18.1, C19.1, C20.1, C51.1, C52.1, C55.1, R6.1, R7.1, R21.1, U5.2 (VIN), U6.2 (VIN), U11.2 (VIN); also elsewhere on the board

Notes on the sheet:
12V Supply for Low Voltage Clean Channels @2A / 24W CHANNEL C
5V clean Channel Power supply @3A / 15W CHANNEL C
5V clean Channel Power supply @3A / 15W CHANNEL D
3V3 clean Channel Power supply @3A / 9.9W CHANNEL C
3V3 Logic Power supply @1A / 3.3W (could go up to 6.6W) CHANNEL A
12V Supply for Low Voltage Clean Channels @2A / 24W CHANNEL D

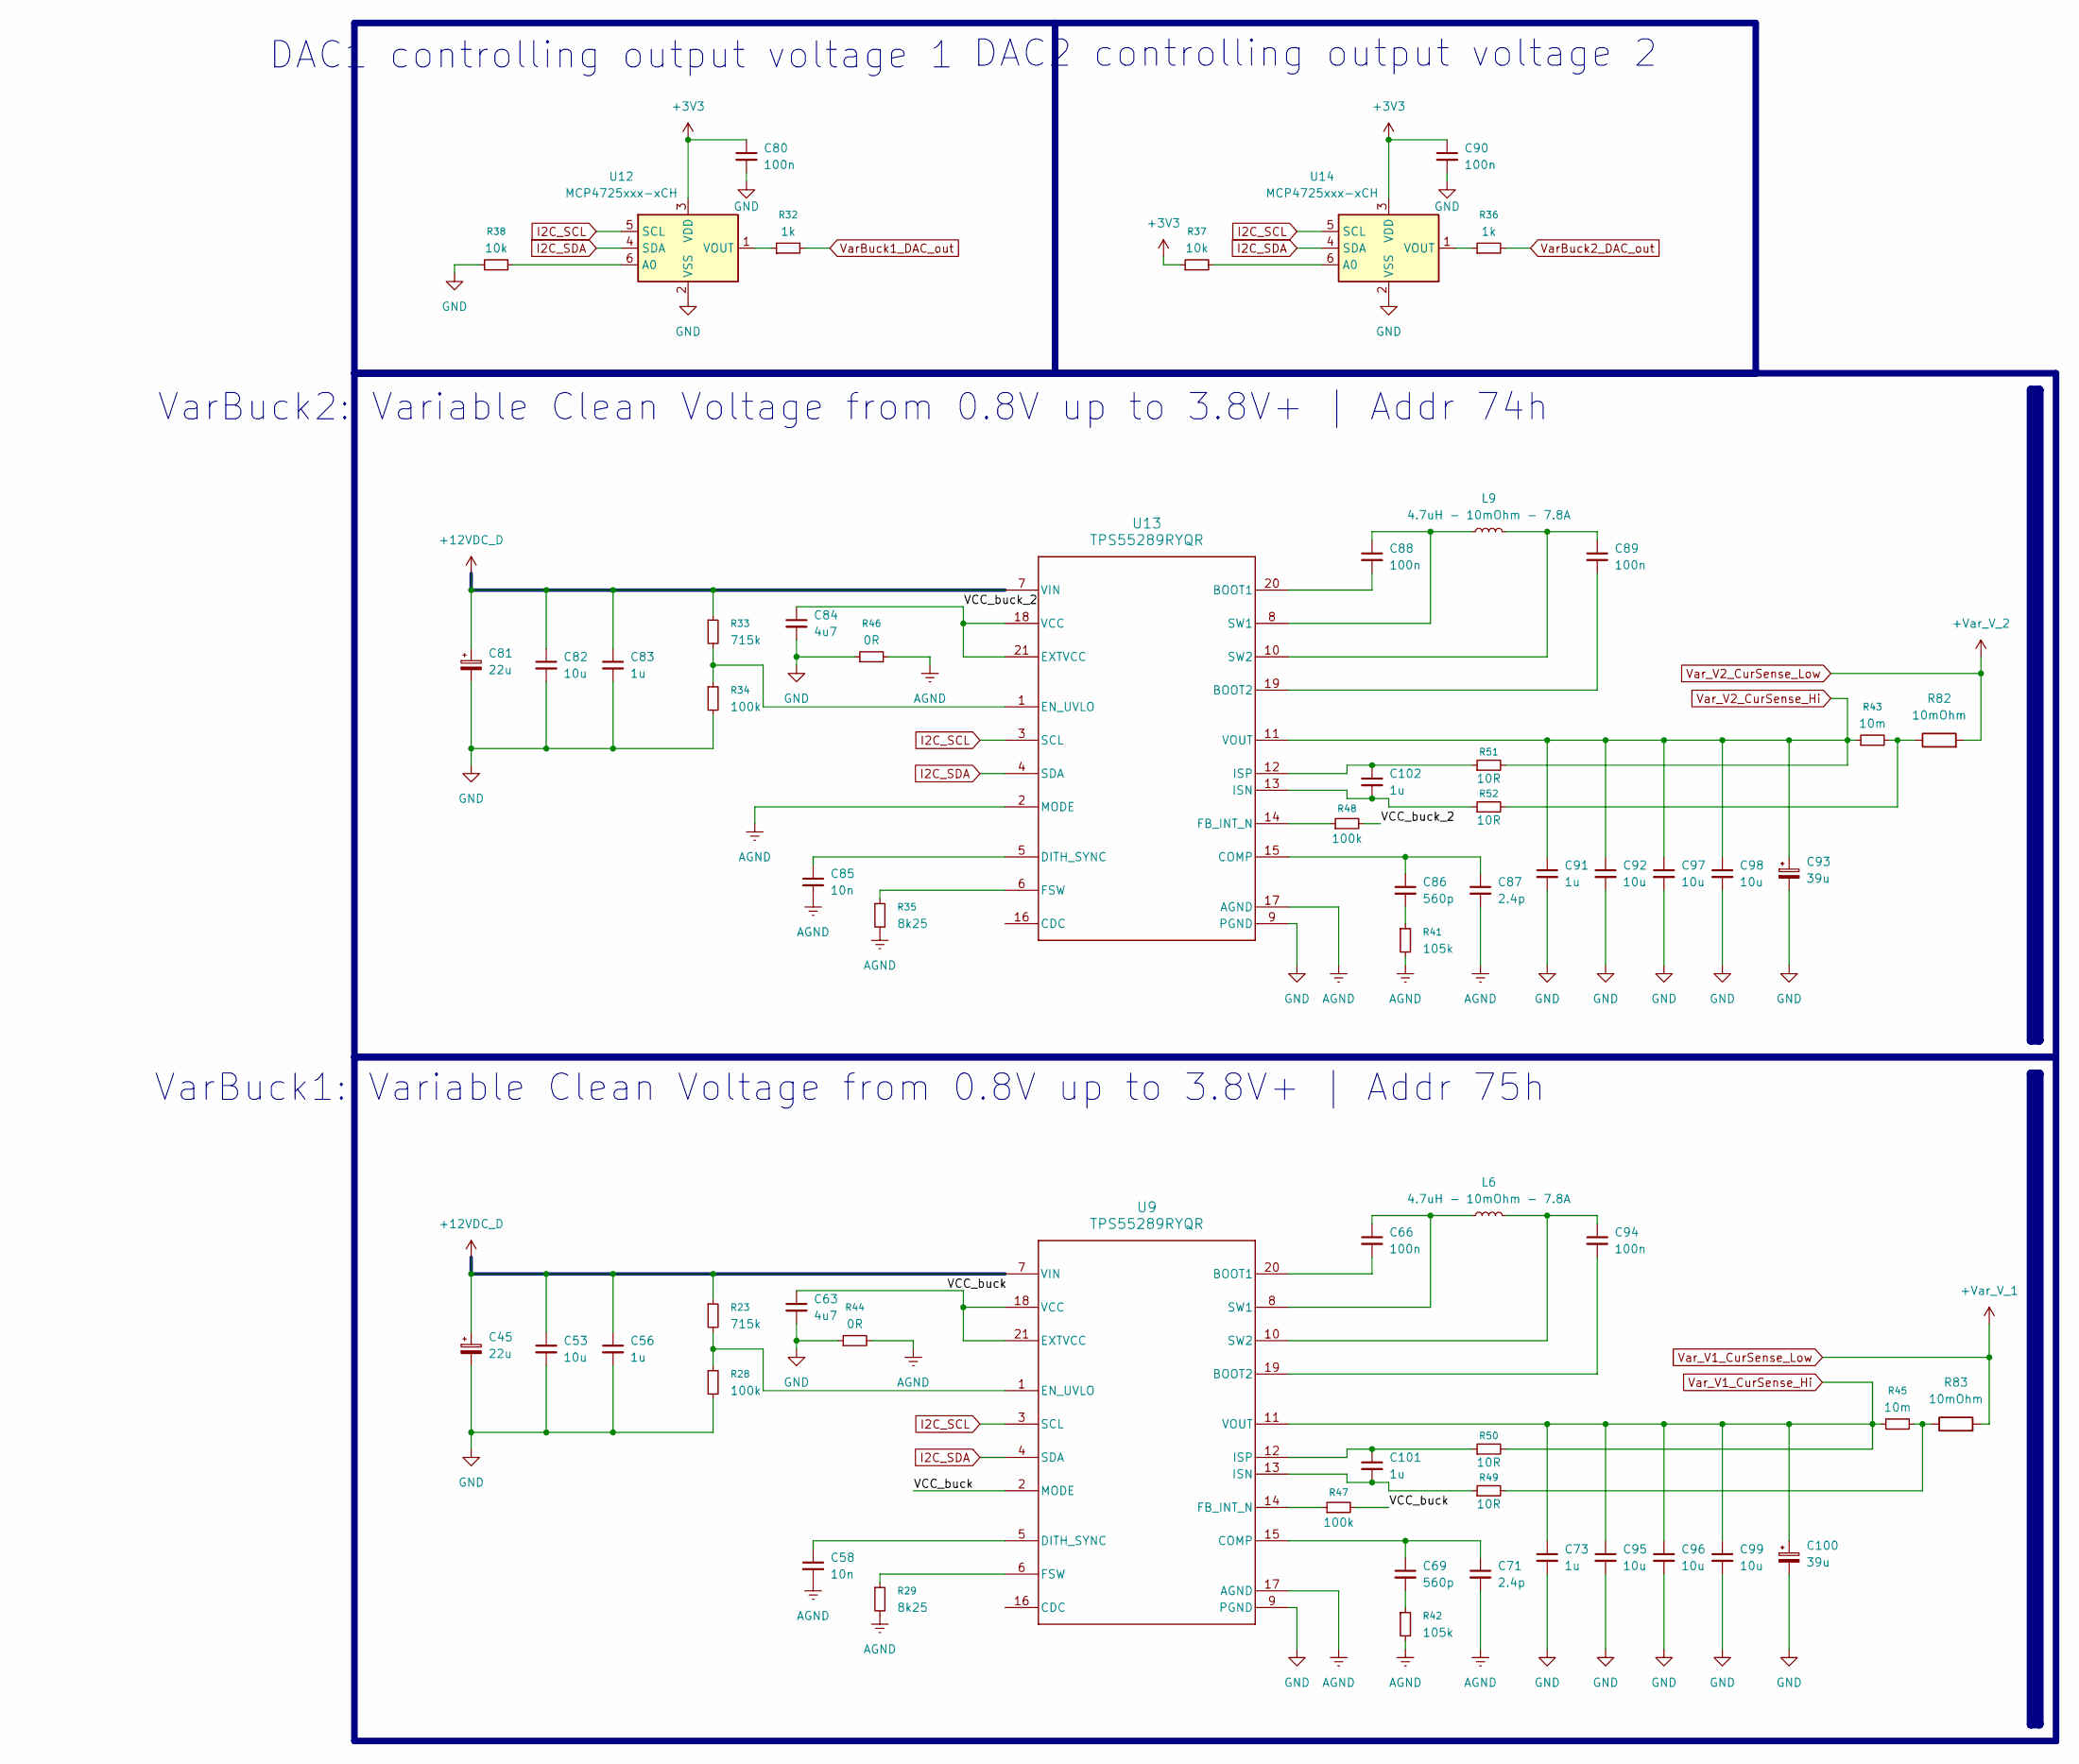
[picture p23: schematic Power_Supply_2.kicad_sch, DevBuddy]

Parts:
C45, C81: 22u; CP_EIA-7343-31_Kemet-D
C53, C82: 10u; C_1210_3225Metric
C56, C83, C101, C102: 1u; C_0402_1005Metric
C58, C85: 10n; C_0402_1005Metric
C63, C84: 4u7; C_0603_1608Metric
C66, C88, C89, C94: 100n; C_0603_1608Metric
C69, C86: 560p; C_0402_1005Metric
C71, C87: 2.4p; C_0402_1005Metric
C73, C91: 1u; C_0603_1608Metric
C80, C90: 100n; C_0402_1005Metric
C92, C95, C96, C97, C98, C99: 10u; C_0805_2012Metric
C93, C100: 39u; CP_Elec_5x5.9
L6, L9: 4.7uH - 10mOhm - 7.8A; L_Bourns-SRN8040_8x8.15mm
R23, R33: 715k; R_0402_1005Metric
R28, R34, R47, R48: 100k; R_0402_1005Metric
R29, R35: 8k25; R_0402_1005Metric
R32, R36: 1k; R_0402_1005Metric
R37, R38: 10k; R_0402_1005Metric
R41, R42: 105k; R_0402_1005Metric
R43, R45: 10m; R_1206_3216Metric
R44, R46: 0R; R_0402_1005Metric
R49, R50, R51, R52: 10R; R_0402_1005Metric
R82, R83: 10mOhm; R_1210_3225Metric
U9, U13: TPS55289RYQR; RYQ0021A-MFG
U12, U14: MCP4725xxx-xCH; SOT-23-6

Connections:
12V_D_CurSense_Low: C45.1, C53.1, C56.1, C81.1, C82.1, C83.1, R23.1, R33.1, U9.7 (VIN), U13.7 (VIN); also elsewhere on the board
+3V3: C80.1, C90.1, R37.1, U12.3 (VDD), U14.3 (VDD); also elsewhere on the board
/Power_Supply_2/VCC_buck: C63.1, R47.2, U9.2 (MODE), U9.18 (VCC), U9.21 (EXTVCC)
/Power_Supply_2/VCC_buck_2: C84.1, R48.2, U13.18 (VCC), U13.21 (EXTVCC)
AGND: C58.2, C71.2, C85.2, C87.2, R29.2, R35.2, R41.2, R42.2, R44.2, R46.2, U9.17 (AGND), U13.2 (MODE), U13.17 (AGND)
GND: C45.2, C53.2, C56.2, C63.2, C73.2, C80.2, C81.2, C82.2, C83.2, C84.2, C90.2, C91.2, C92.2, C93.2, C95.2, C96.2, C97.2, C98.2, C99.2, C100.2, R28.2, R34.2, R38.1, R44.1, R46.1, U9.9 (PGND), U12.2 (VSS), U13.9 (PGND), U14.2 (VSS); also elsewhere on the board
I2C_SCL: U9.3 (SCL), U12.5 (SCL), U13.3 (SCL), U14.5 (SCL); also elsewhere on the board
I2C_SDA: U9.4 (SDA), U12.4 (SDA), U13.4 (SDA), U14.4 (SDA); also elsewhere on the board
unnamed: C69.2, R42.1
unnamed: C86.2, R41.1
unnamed: R43.2, R52.2, R82.1
unnamed: R45.2, R49.2, R83.1
unnamed: C66.2, U9.20 (BOOT1)
unnamed: C94.2, U9.19 (BOOT2)
unnamed: C69.1, C71.1, U9.15 (COMP)
unnamed: C58.1, U9.5 (DITH_SYNC)
unnamed: R23.2, R28.1, U9.1 (EN_UVLO)
unnamed: R47.1, U9.14 (FB_INT_N)
unnamed: R29.1, U9.6 (FSW)
unnamed: C101.2, R49.1, U9.13 (ISN)
unnamed: C101.1, R50.1, U9.12 (ISP)
unnamed: C66.1, L6.1, U9.8 (SW1)
unnamed: C94.1, L6.2, U9.10 (SW2)
unnamed: R38.2, U12.6 (A0)
unnamed: R32.1, U12.1 (VOUT)
unnamed: C88.2, U13.20 (BOOT1)
unnamed: C89.2, U13.19 (BOOT2)
unnamed: C86.1, C87.1, U13.15 (COMP)
unnamed: C85.1, U13.5 (DITH_SYNC)
unnamed: R33.2, R34.1, U13.1 (EN_UVLO)
unnamed: R48.1, U13.14 (FB_INT_N)
unnamed: R35.1, U13.6 (FSW)
unnamed: C102.2, R52.1, U13.13 (ISN)
unnamed: C102.1, R51.1, U13.12 (ISP)
unnamed: C88.1, L9.1, U13.8 (SW1)
unnamed: C89.1, L9.2, U13.10 (SW2)
unnamed: R37.2, U14.6 (A0)
unnamed: R36.1, U14.1 (VOUT)
VarBuck1_DAC_out: R32.2; also elsewhere on the board
VarBuck2_DAC_out: R36.2; also elsewhere on the board
Var_V1_CurSense_Hi: C73.1, C95.1, C96.1, C99.1, C100.1, R45.1, R50.2, U9.11 (VOUT); also elsewhere on the board
Var_V1_CurSense_Low: R83.2; also elsewhere on the board
Var_V2_CurSense_Hi: C91.1, C92.1, C93.1, C97.1, C98.1, R43.1, R51.2, U13.11 (VOUT); also elsewhere on the board
Var_V2_CurSense_Low: R82.2; also elsewhere on the board

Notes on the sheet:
DAC1 controlling output voltage 1
VarBuck2: Variable Clean Voltage from 0.8V up to 3.8V+ | Addr 74h
VarBuck1: Variable Clean Voltage from 0.8V up to 3.8V+ | Addr 75h
DAC2 controlling output voltage 2

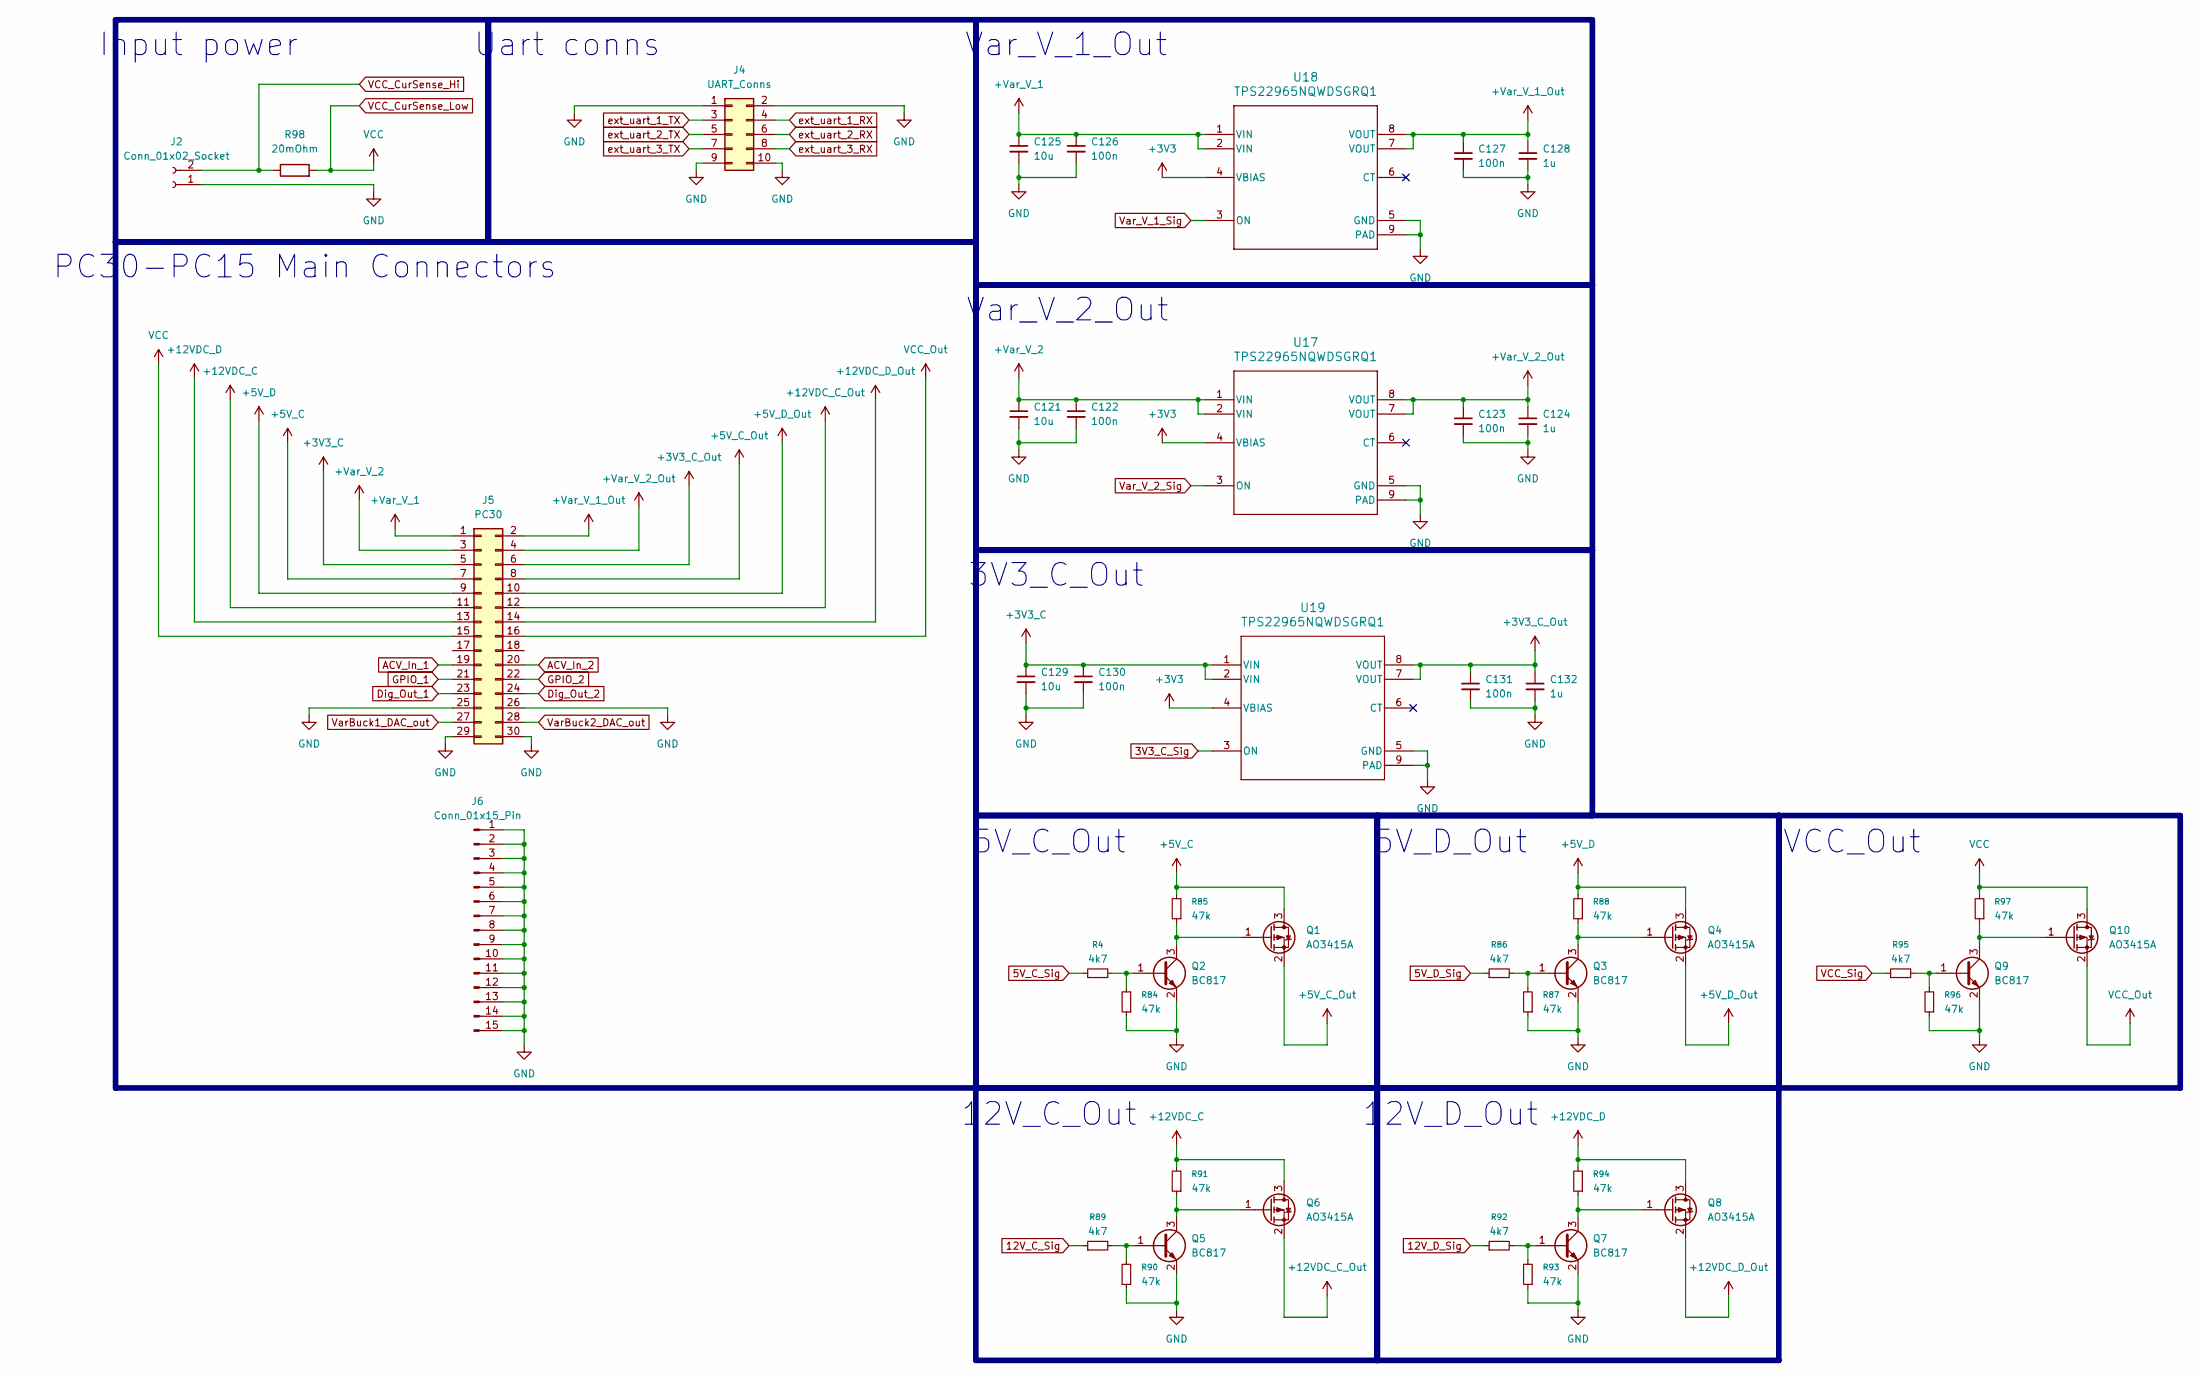
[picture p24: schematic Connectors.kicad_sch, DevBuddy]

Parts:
C121, C125, C129: 10u; C_1210_3225Metric
C122, C123, C126, C127, C130, C131: 100n; C_0402_1005Metric
C124, C128, C132: 1u; C_0402_1005Metric
J2: Conn_01x02_Socket; PhoenixContact_MC_1,5_2-G-5.08_1x02_P5.08mm_Horizontal
J4: UART_Conns; PinHeader_2x05_P2.54mm_Vertical_SMD
J5: PC30; PinHeader_2x15_P2.54mm_Vertical_SMD
J6: Conn_01x15_Pin; PinHeader_1x15_P2.54mm_Vertical_SMD_Pin1Left
Q1, Q4, Q6, Q8, Q10: AO3415A; SOT-23
Q2, Q3, Q5, Q7, Q9: BC817; SOT-23
R4, R86, R89, R92, R95: 4k7; R_0402_1005Metric
R84, R85, R87, R88, R90, R91, R93, R94, R96, R97: 47k; R_0402_1005Metric
R98: 20mOhm; R_1210_3225Metric
U17, U18, U19: TPS22965NQWDSGRQ1; DSG0008A_NV

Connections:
3V3_C_CurSense_Low: C129.1, C130.1, J5.5, U19.1 (VIN), U19.2 (VIN); also elsewhere on the board
3V3_C_Sig: U19.3 (ON); also elsewhere on the board
5V_C_CurSense_Low: J5.7, Q1.3 (D), R85.2; also elsewhere on the board
5V_C_Sig: R4.1; also elsewhere on the board
5V_D_CurSense_Low: J5.9, Q4.3 (D), R88.2; also elsewhere on the board
5V_D_Sig: R86.1; also elsewhere on the board
12V_C_CurSense_Low: J5.11, Q6.3 (D), R91.2; also elsewhere on the board
12V_C_Sig: R89.1; also elsewhere on the board
12V_D_CurSense_Low: J5.13, Q8.3 (D), R94.2; also elsewhere on the board
12V_D_Sig: R92.1; also elsewhere on the board
+3V3: U17.4 (VBIAS), U18.4 (VBIAS), U19.4 (VBIAS); also elsewhere on the board
+3V3_C_Out: C131.1, C132.1, J5.6, U19.7 (VOUT), U19.8 (VOUT)
+5V_C_Out: J5.8, Q1.2 (S)
+5V_D_Out: J5.10, Q4.2 (S)
+12VDC_C_Out: J5.12, Q6.2 (S)
+12VDC_D_Out: J5.14, Q8.2 (S)
+Var_V_1_Out: C127.1, C128.1, J5.2, U18.7 (VOUT), U18.8 (VOUT)
+Var_V_2_Out: C123.1, C124.1, J5.4, U17.7 (VOUT), U17.8 (VOUT)
ACV_In_1: J5.19; also elsewhere on the board
ACV_In_2: J5.20; also elsewhere on the board
Dig_Out_1: J5.23; also elsewhere on the board
Dig_Out_2: J5.24; also elsewhere on the board
GND: C121.2, C122.2, C123.2, C124.2, C125.2, C126.2, C127.2, C128.2, C129.2, C130.2, C131.2, C132.2, J2.1, J4.1, J4.2, J4.9, J4.10, J5.25, J5.26, J5.29, J5.30, J6.1, J6.2, J6.3, J6.4, J6.5, J6.6, J6.7, J6.8, J6.9, J6.10, J6.11, J6.12, J6.13, J6.14, J6.15, Q2.2 (E), Q3.2 (E), Q5.2 (E), Q7.2 (E), Q9.2 (E), R84.1, R87.1, R90.1, R93.1, R96.1, U17.5 (GND), U17.9 (PAD), U18.5 (GND), U18.9 (PAD), U19.5 (GND), U19.9 (PAD); also elsewhere on the board
GPIO_1: J5.21; also elsewhere on the board
GPIO_2: J5.22; also elsewhere on the board
unnamed: Q1.1 (G), Q2.3 (C), R85.1
unnamed: Q2.1 (B), R4.2, R84.2
unnamed: Q3.1 (B), R86.2, R87.2
unnamed: Q3.3 (C), Q4.1 (G), R88.1
unnamed: Q5.1 (B), R89.2, R90.2
unnamed: Q5.3 (C), Q6.1 (G), R91.1
unnamed: Q7.1 (B), R92.2, R93.2
unnamed: Q7.3 (C), Q8.1 (G), R94.1
unnamed: Q9.1 (B), R95.2, R96.2
unnamed: Q9.3 (C), Q10.1 (G), R97.1
VCC_CurSense_Hi: J2.2, R98.1; also elsewhere on the board
VCC_CurSense_Low: J5.15, Q10.3 (D), R97.2, R98.2; also elsewhere on the board
VCC_Out: J5.16, Q10.2 (S)
VCC_Sig: R95.1; also elsewhere on the board
VarBuck1_DAC_out: J5.27; also elsewhere on the board
VarBuck2_DAC_out: J5.28; also elsewhere on the board
Var_V1_CurSense_Low: C125.1, C126.1, J5.1, U18.1 (VIN), U18.2 (VIN); also elsewhere on the board
Var_V2_CurSense_Low: C121.1, C122.1, J5.3, U17.1 (VIN), U17.2 (VIN); also elsewhere on the board
Var_V_1_Sig: U18.3 (ON); also elsewhere on the board
Var_V_2_Sig: U17.3 (ON); also elsewhere on the board
ext_uart_1_RX: J4.4; also elsewhere on the board
ext_uart_1_TX: J4.3; also elsewhere on the board
ext_uart_2_RX: J4.6; also elsewhere on the board
ext_uart_2_TX: J4.5; also elsewhere on the board
ext_uart_3_RX: J4.8; also elsewhere on the board
ext_uart_3_TX: J4.7; also elsewhere on the board

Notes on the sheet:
Input power
5V_D_Out
12V_D_Out
VCC_Out
Var_V_1_Out
3V3_C_Out
PC30-PC15 Main Connectors
Uart conns
12V_C_Out
5V_C_Out
Var_V_2_Out

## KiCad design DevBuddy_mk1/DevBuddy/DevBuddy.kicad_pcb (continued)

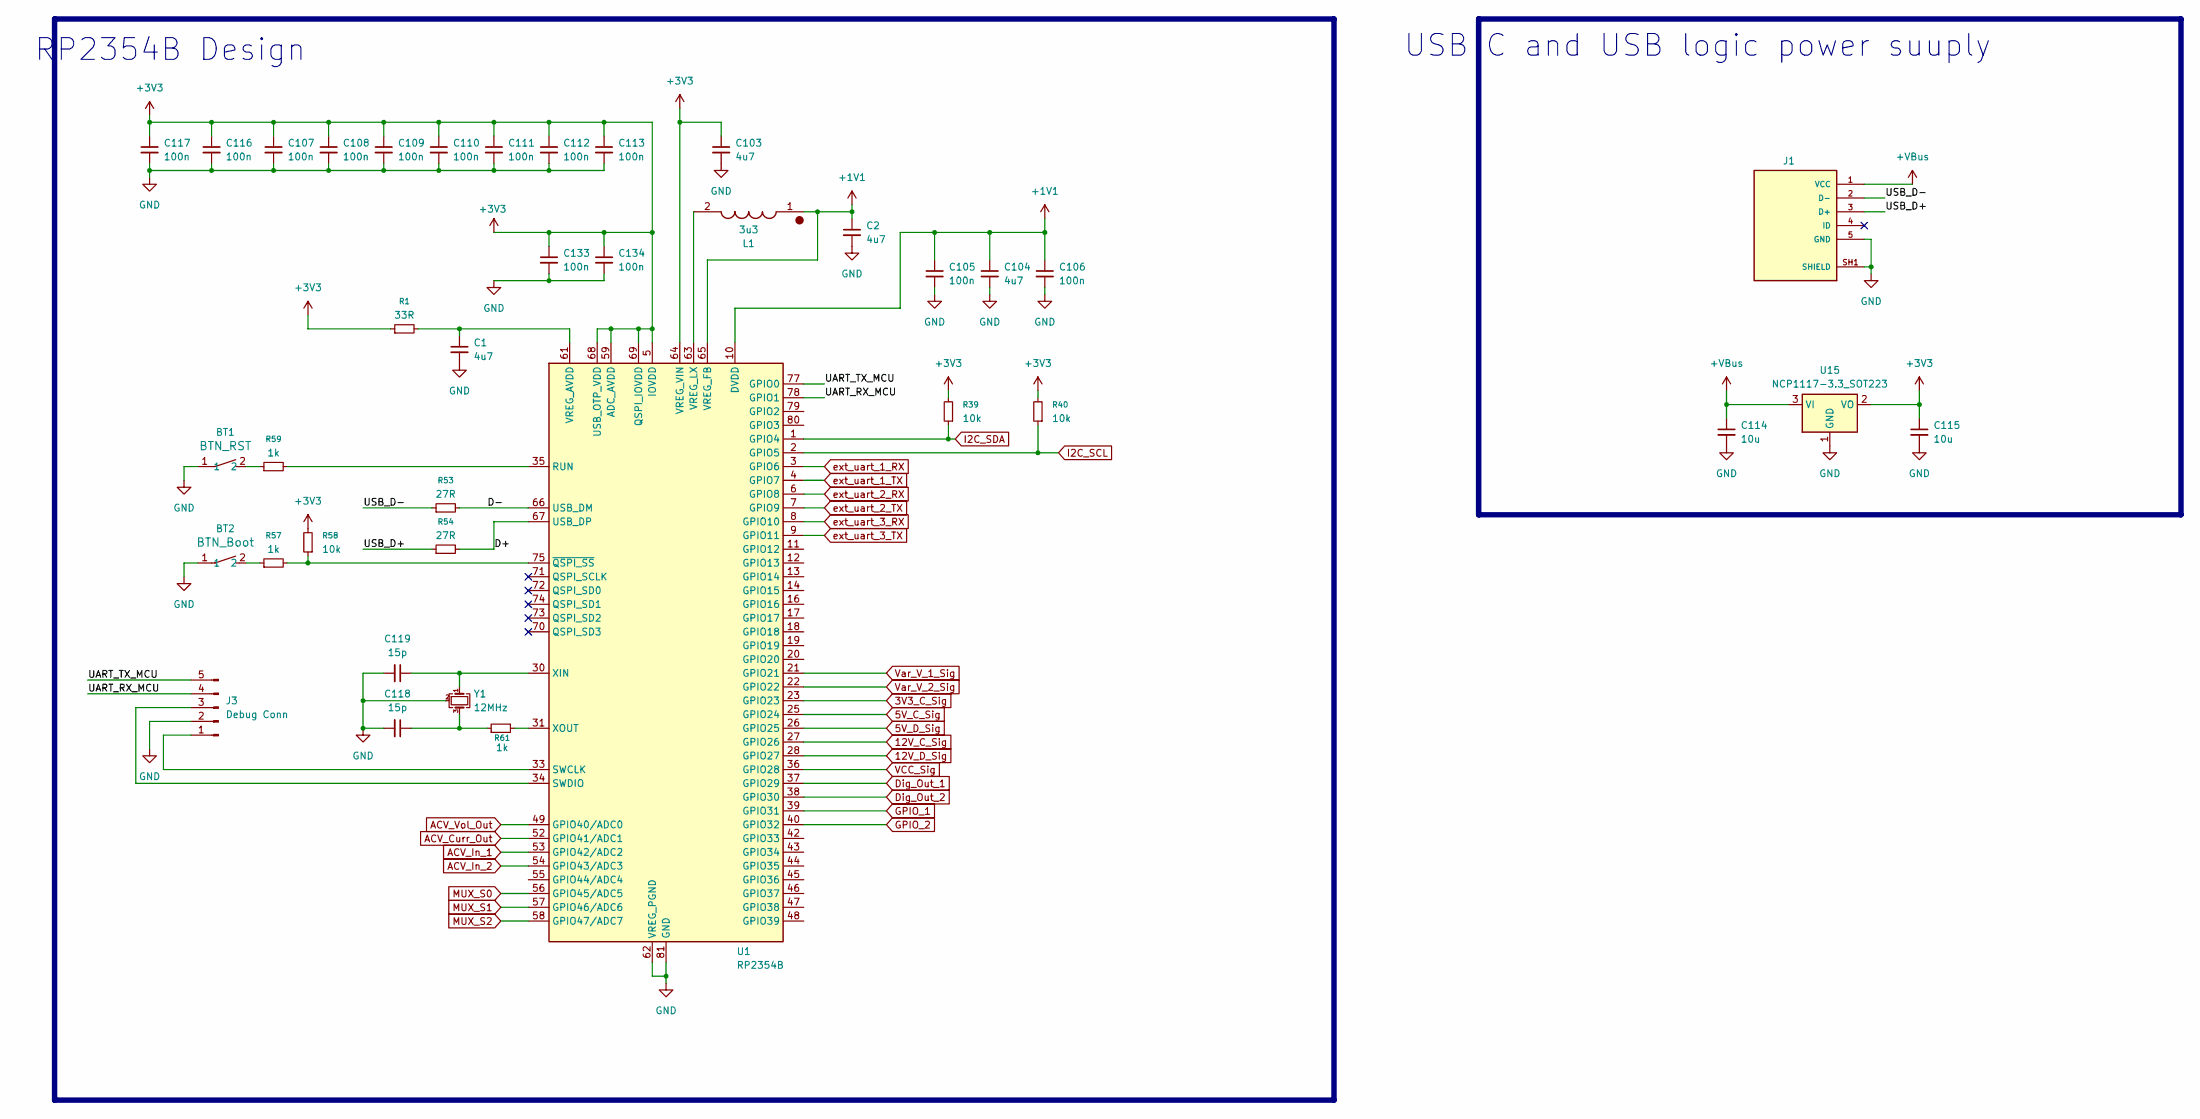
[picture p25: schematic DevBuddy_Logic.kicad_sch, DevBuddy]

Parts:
BT1: BTN_RST; B3U-1000P
BT2: BTN_Boot; B3U-1000P
C1, C2, C103, C104: 4u7; C_0402_1005Metric
C105, C106, C107, C108, C109, C110, C111, C112, C113, C116, C117, C133, C134: 100n; C_0402_1005Metric
C114, C115: 10u; C_0805_2012Metric
C118, C119: 15p; C_0402_1005Metric
J1: 10118194-0001LF; AMPHENOL_10118194-0001LF; PARTREV D
J3: Debug Conn; PinHeader_1x05_P2.54mm_Vertical_SMD_Pin1Left
L1: 3u3; AOTAB201610S3R3101T; Mouser Part Number 815-AB201610S3R3101T
R1: 33R; R_0402_1005Metric
R39, R40, R58: 10k; R_0402_1005Metric
R53, R54: 27R; R_0402_1005Metric
R57, R59, R61: 1k; R_0402_1005Metric
U1: RP2354B; QFN-80-1EP_10x10mm_P0.4mm_EP3.4x3.4mm
U15: NCP1117-3.3_SOT223; SOT-223-3_TabPin2
Y1: 12MHz; Crystal_SMD_3225-4Pin_3.2x2.5mm

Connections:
3V3_C_Sig: U1.23 (GPIO23); also elsewhere on the board
5V_C_Sig: U1.25 (GPIO24); also elsewhere on the board
5V_D_Sig: U1.26 (GPIO25); also elsewhere on the board
12V_C_Sig: U1.27 (GPIO26); also elsewhere on the board
12V_D_Sig: U1.28 (GPIO27); also elsewhere on the board
+1V1: C2.1, C104.1, C105.1, C106.1, L1.1, U1.10 (DVDD), U1.32 (DVDD), U1.51 (DVDD), U1.65 (VREG_FB)
+3V3: C103.1, C107.1, C108.1, C109.1, C110.1, C111.1, C112.1, C113.1, C115.1, C116.1, C117.1, C133.1, C134.1, R1.1, R39.2, R40.2, R58.2, U1.5 (IOVDD), U1.15 (IOVDD), U1.24 (IOVDD), U1.29 (IOVDD), U1.41 (IOVDD), U1.50 (IOVDD), U1.59 (ADC_AVDD), U1.60 (IOVDD), U1.64 (VREG_VIN), U1.68 (USB_OTP_VDD), U1.69 (QSPI_IOVDD), U1.76 (IOVDD), U15.2 (VO); also elsewhere on the board
+VBus: C114.1, J1.1 (VCC), U15.3 (VI)
/DevBuddy_Logic/D+: R54.2, U1.67 (USB_DP)
/DevBuddy_Logic/D-: R53.2, U1.66 (USB_DM)
/DevBuddy_Logic/UART_RX_MCU: J3.4, U1.78 (GPIO1)
/DevBuddy_Logic/UART_TX_MCU: J3.5, U1.77 (GPIO0)
/DevBuddy_Logic/USB_D+: J1.3 (D+), R54.1
/DevBuddy_Logic/USB_D-: J1.2 (D-), R53.1
ACV_Curr_Out: U1.52 (GPIO41/ADC1); also elsewhere on the board
ACV_In_1: U1.53 (GPIO42/ADC2); also elsewhere on the board
ACV_In_2: U1.54 (GPIO43/ADC3); also elsewhere on the board
ACV_Vol_Out: U1.49 (GPIO40/ADC0); also elsewhere on the board
Dig_Out_1: U1.37 (GPIO29); also elsewhere on the board
Dig_Out_2: U1.38 (GPIO30); also elsewhere on the board
GND: BT1.1, BT2.1, C1.2, C2.2, C103.2, C104.2, C105.2, C106.2, C107.2, C108.2, C109.2, C110.2, C111.2, C112.2, C113.2, C114.2, C115.2, C116.2, C117.2, C118.2, C119.2, C133.2, C134.2, J1.5 (GND), J1.SH1 (SHIELD), J1.SH2 (SHIELD), J1.SH3 (SHIELD), J1.SH4 (SHIELD), J1.SH5 (SHIELD), J1.SH6 (SHIELD), J3.2, U1.62 (VREG_PGND), U1.81 (GND), U15.1 (GND), Y1.2 (G), Y1.4 (G); also elsewhere on the board
GPIO_1: U1.39 (GPIO31); also elsewhere on the board
GPIO_2: U1.40 (GPIO32); also elsewhere on the board
I2C_SCL: R40.1, U1.2 (GPIO5); also elsewhere on the board
I2C_SDA: R39.1, U1.1 (GPIO4); also elsewhere on the board
MUX_S0: U1.56 (GPIO45/ADC5); also elsewhere on the board
MUX_S1: U1.57 (GPIO46/ADC6); also elsewhere on the board
MUX_S2: U1.58 (GPIO47/ADC7); also elsewhere on the board
unnamed: BT1.2, R59.1
unnamed: BT2.2, R57.1
unnamed: C118.1, R61.1, Y1.3
unnamed: J3.1, U1.33 (SWCLK)
unnamed: J3.3, U1.34 (SWDIO)
unnamed: R59.2, U1.35 (RUN)
unnamed: C1.1, R1.2, U1.61 (VREG_AVDD)
unnamed: L1.2, U1.63 (VREG_LX)
unnamed: C119.1, U1.30 (XIN), Y1.1
unnamed: R61.2, U1.31 (XOUT)
unnamed: R57.2, R58.1, U1.75 (~QSPI_SS)
VCC_Sig: U1.36 (GPIO28); also elsewhere on the board
Var_V_1_Sig: U1.21 (GPIO21); also elsewhere on the board
Var_V_2_Sig: U1.22 (GPIO22); also elsewhere on the board
ext_uart_1_RX: U1.3 (GPIO6); also elsewhere on the board
ext_uart_1_TX: U1.4 (GPIO7); also elsewhere on the board
ext_uart_2_RX: U1.6 (GPIO8); also elsewhere on the board
ext_uart_2_TX: U1.7 (GPIO9); also elsewhere on the board
ext_uart_3_RX: U1.8 (GPIO10); also elsewhere on the board
ext_uart_3_TX: U1.9 (GPIO11); also elsewhere on the board

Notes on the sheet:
RP2354B Design
USB C and USB logic power suuply

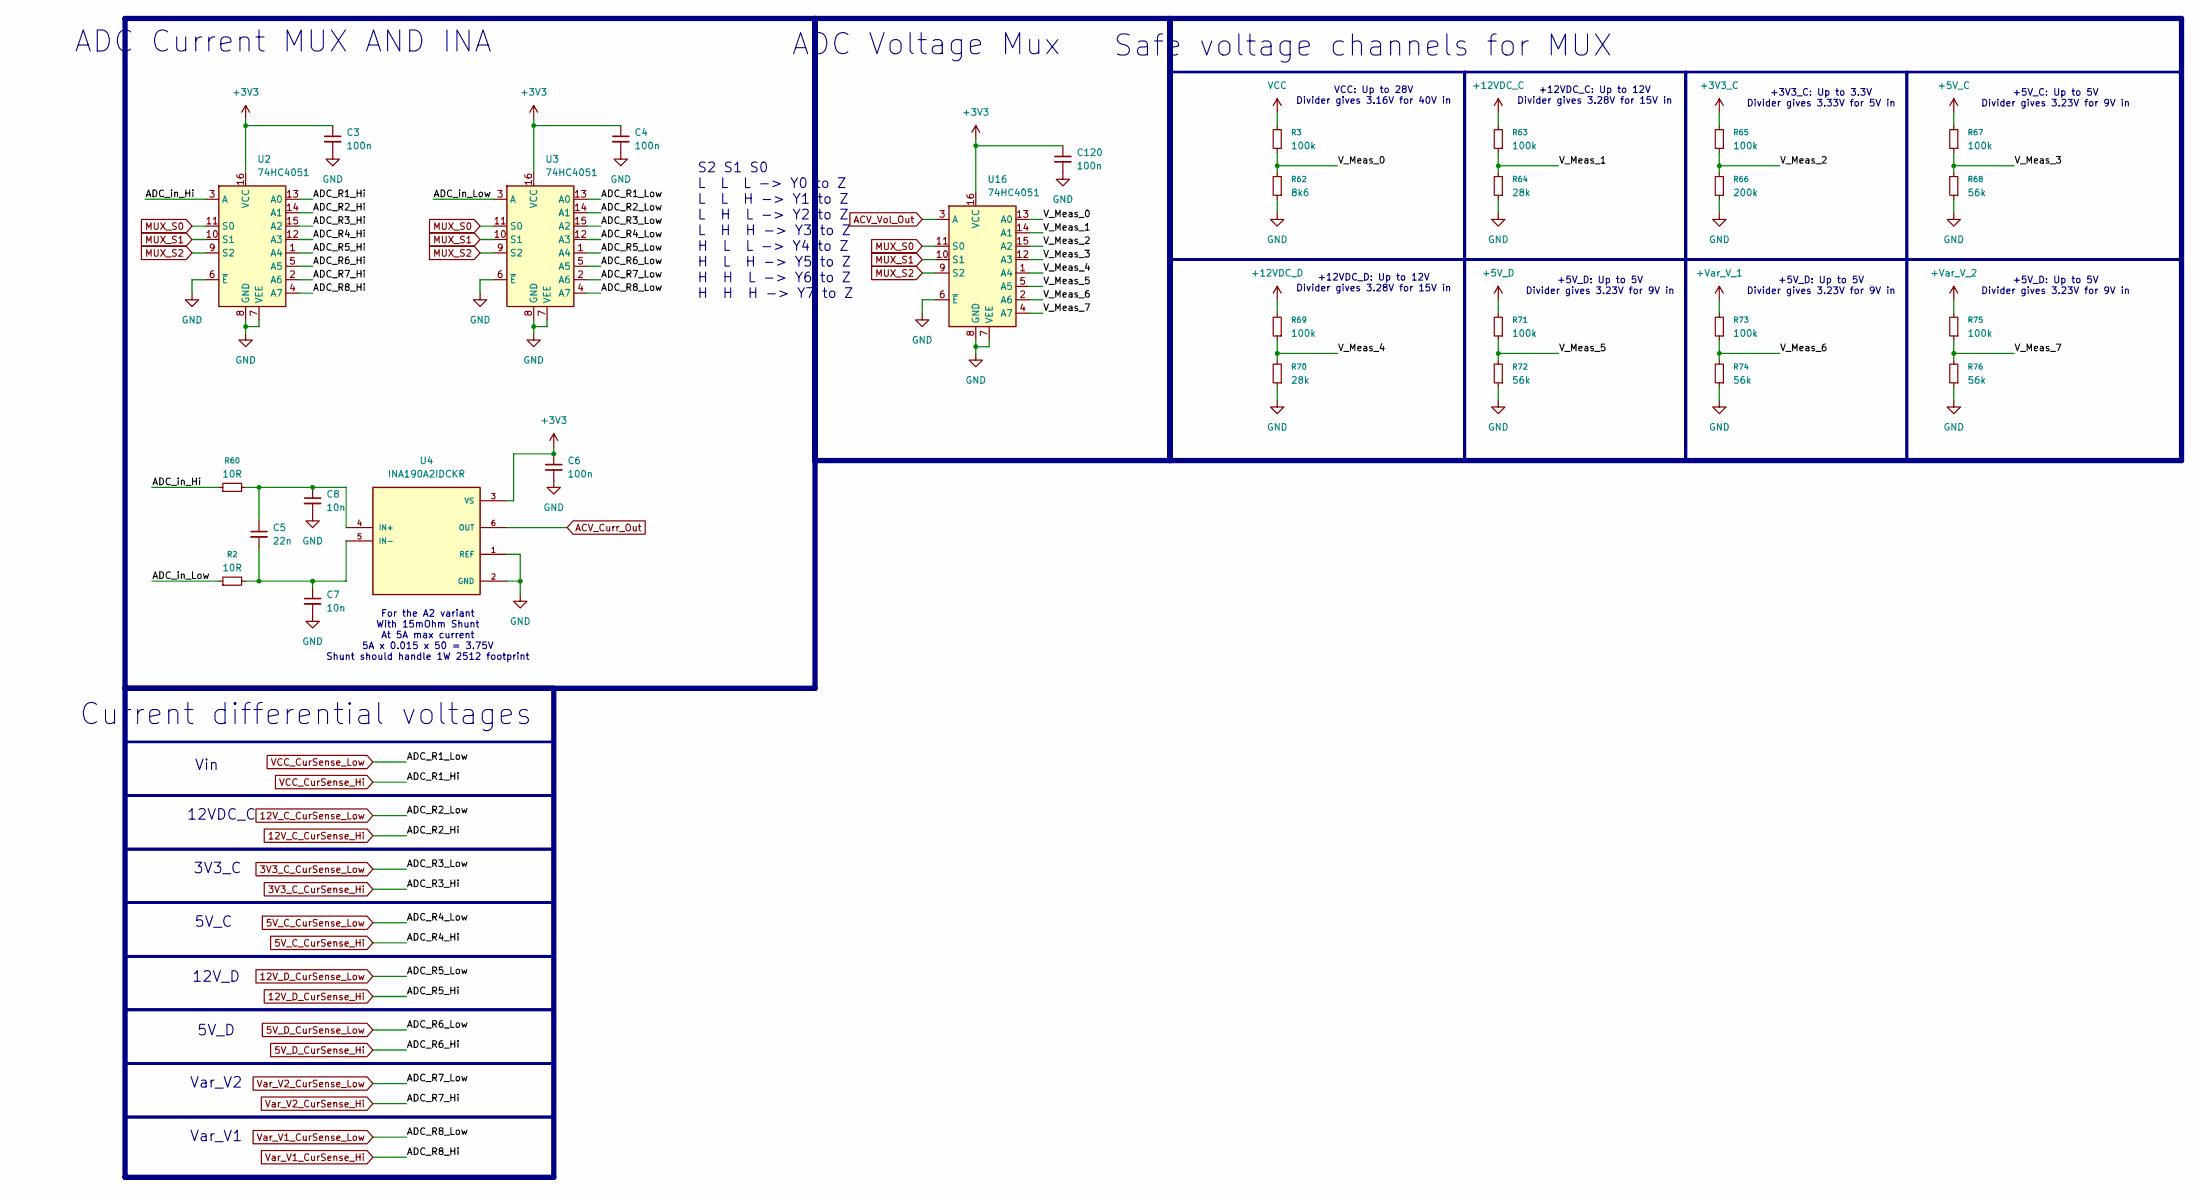
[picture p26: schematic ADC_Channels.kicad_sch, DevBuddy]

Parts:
C3, C4, C6, C120: 100n; C_0402_1005Metric
C5: 22n; C_0402_1005Metric
C7, C8: 10n; C_0402_1005Metric
R2, R60: 10R; R_0402_1005Metric
R3, R63, R65, R67, R69, R71, R73, R75: 100k; R_0402_1005Metric
R62: 8k6; R_0402_1005Metric
R64, R70: 28k; R_0402_1005Metric
R66: 200k; R_0402_1005Metric
R68, R72, R74, R76: 56k; R_0402_1005Metric
U2, U3, U16: 74HC4051; SOIC-16_3.9x9.9mm_P1.27mm
U4: INA190A2IDCKR; IC_INA190A2IDCKR; PARTREV D

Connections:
3V3_C_CurSense_Hi: U2.15 (A2); also elsewhere on the board
3V3_C_CurSense_Low: R65.2, U3.15 (A2); also elsewhere on the board
5V_C_CurSense_Hi: U2.12 (A3); also elsewhere on the board
5V_C_CurSense_Low: R67.2, U3.12 (A3); also elsewhere on the board
5V_D_CurSense_Hi: U2.5 (A5); also elsewhere on the board
5V_D_CurSense_Low: R71.2, U3.5 (A5); also elsewhere on the board
12V_C_CurSense_Hi: U2.14 (A1); also elsewhere on the board
12V_C_CurSense_Low: R63.2, U3.14 (A1); also elsewhere on the board
12V_D_CurSense_Hi: U2.1 (A4); also elsewhere on the board
12V_D_CurSense_Low: R69.2, U3.1 (A4); also elsewhere on the board
+3V3: C3.1, C4.1, C6.1, C120.1, U2.16 (VCC), U3.16 (VCC), U4.3 (VS), U16.16 (VCC); also elsewhere on the board
/ADC_Channels/ADC_in_Hi: R60.1, U2.3 (A)
/ADC_Channels/ADC_in_Low: R2.1, U3.3 (A)
/ADC_Channels/V_Meas_0: R3.1, R62.2, U16.13 (A0)
/ADC_Channels/V_Meas_1: R63.1, R64.2, U16.14 (A1)
/ADC_Channels/V_Meas_2: R65.1, R66.2, U16.15 (A2)
/ADC_Channels/V_Meas_3: R67.1, R68.2, U16.12 (A3)
/ADC_Channels/V_Meas_4: R69.1, R70.2, U16.1 (A4)
/ADC_Channels/V_Meas_5: R71.1, R72.2, U16.5 (A5)
/ADC_Channels/V_Meas_6: R73.1, R74.2, U16.2 (A6)
/ADC_Channels/V_Meas_7: R75.1, R76.2, U16.4 (A7)
ACV_Curr_Out: U4.6 (OUT); also elsewhere on the board
ACV_Vol_Out: U16.3 (A); also elsewhere on the board
GND: C3.2, C4.2, C6.2, C7.2, C8.2, C120.2, R62.1, R64.1, R66.1, R68.1, R70.1, R72.1, R74.1, R76.1, U2.6 (~E), U2.7 (VEE), U2.8 (GND), U3.6 (~E), U3.7 (VEE), U3.8 (GND), U4.1 (REF), U4.2 (GND), U16.6 (~E), U16.7 (VEE), U16.8 (GND); also elsewhere on the board
MUX_S0: U2.11 (S0), U3.11 (S0), U16.11 (S0); also elsewhere on the board
MUX_S1: U2.10 (S1), U3.10 (S1), U16.10 (S1); also elsewhere on the board
MUX_S2: U2.9 (S2), U3.9 (S2), U16.9 (S2); also elsewhere on the board
unnamed: C5.1, C8.1, R60.2, U4.4 (IN+)
unnamed: C5.2, C7.1, R2.2, U4.5 (IN-)
VCC_CurSense_Hi: U2.13 (A0); also elsewhere on the board
VCC_CurSense_Low: R3.2, U3.13 (A0); also elsewhere on the board
Var_V1_CurSense_Hi: U2.4 (A7); also elsewhere on the board
Var_V1_CurSense_Low: R73.2, U3.4 (A7); also elsewhere on the board
Var_V2_CurSense_Hi: U2.2 (A6); also elsewhere on the board
Var_V2_CurSense_Low: R75.2, U3.2 (A6); also elsewhere on the board

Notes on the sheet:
For the A2 variant With 15mOhm Shunt At 5A max current 5A x 0.015 x 50 = 3.75V Shunt should handle 1W 2512 footprint
12VDC_C
+5V_D: Up to 5V Divider gives 3.23V for 9V in
12V_D
Current differential voltages
+5V_C: Up to 5V Divider gives 3.23V for 9V in
S2 S1 S0 L L L -> Y0 to Z L L H -> Y1 to Z L H L -> Y2 to Z L H H -> Y3 to Z H L L -> Y4 to Z H L H -> Y5 to Z H H L -> Y6 to Z H H H -> Y7 to Z
ADC Voltage Mux
Var_V2
+12VDC_D: Up to 12V Divider gives 3.28V for 15V in
+12VDC_C: Up to 12V Divider gives 3.28V for 15V in
Safe voltage channels for MUX
3V3_C
VCC: Up to 28V Divider gives 3.16V for 40V in
+3V3_C: Up to 3.3V Divider gives 3.33V for 5V in
Vin
5V_C
5V_D
ADC Current MUX AND INA
Var_V1

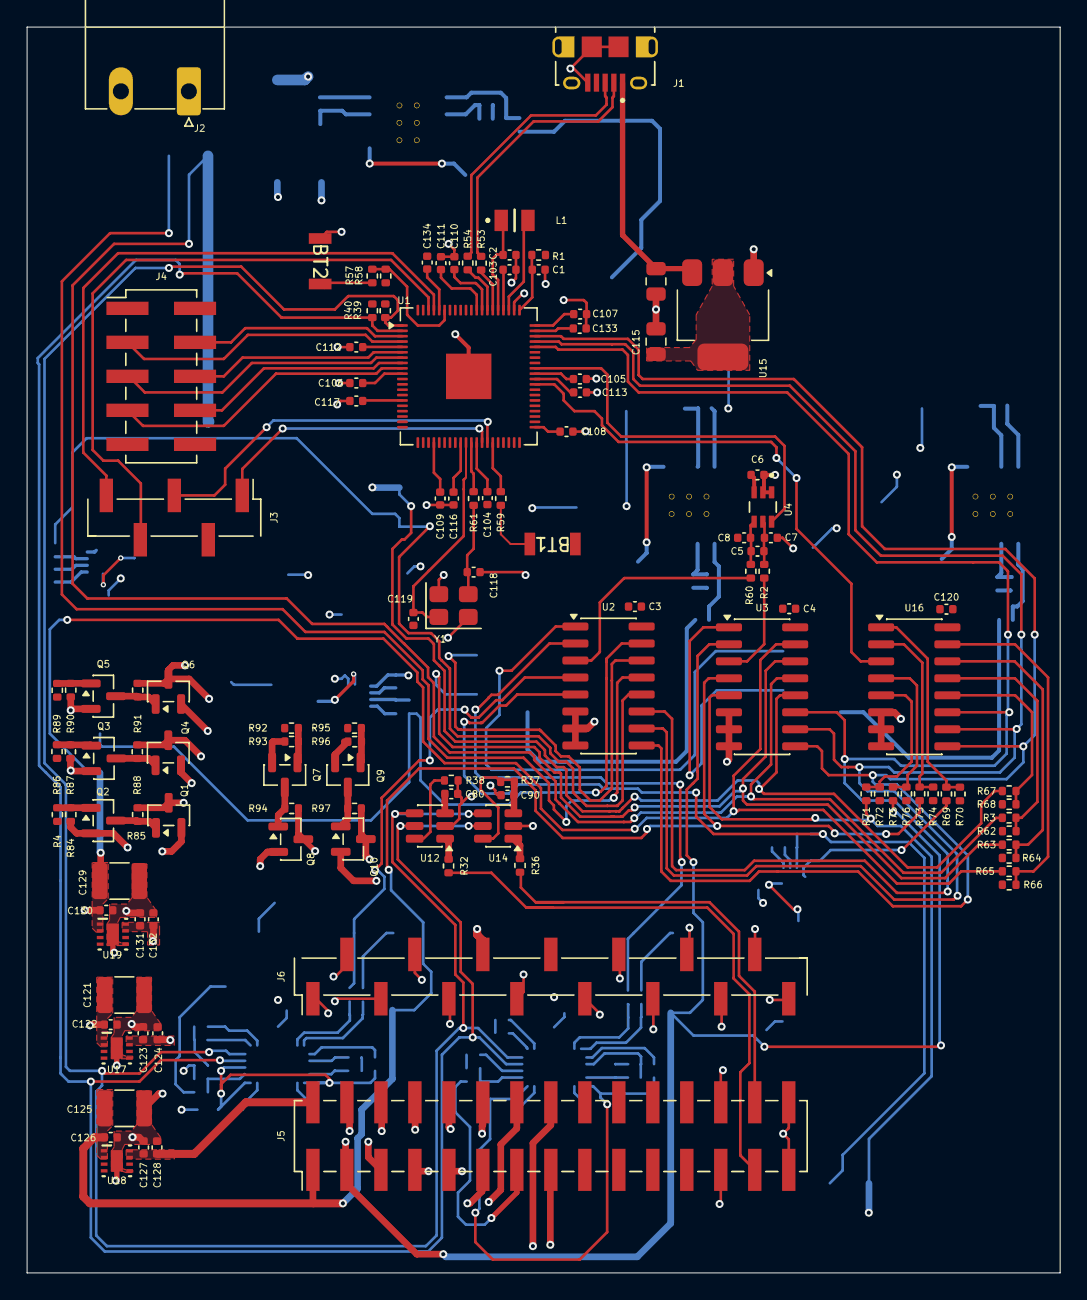
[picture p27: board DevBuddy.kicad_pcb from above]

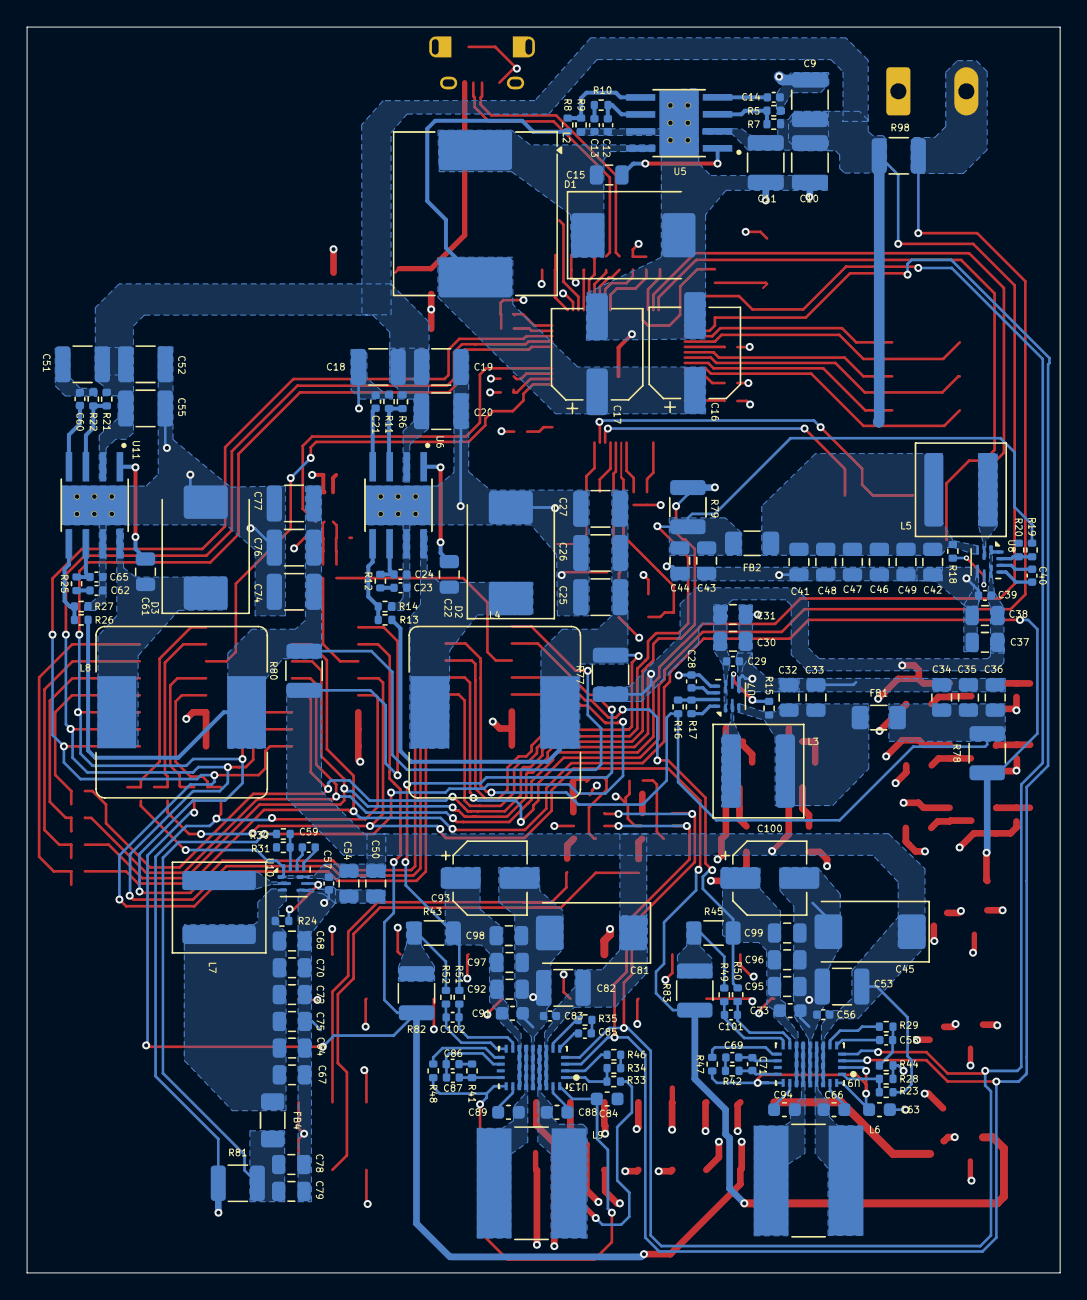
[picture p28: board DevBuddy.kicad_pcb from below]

Board: 4 copper layers, 77.2 x 93.1 mm, 283 parts (164 on the bottom side), 165 nets.

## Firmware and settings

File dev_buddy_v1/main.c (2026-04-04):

/**
 * UART with DMA for RP2350
 */

#include <stdio.h>
#include <string.h>
#include "pico/stdlib.h"
#include "inc/globals.h"
#include "inc/uart_coms.h"
#include "pico/unique_id.h"
#include "pico/multicore.h"
#include "in_out_ctrl.h"
#include "timer_handler.h"
#include "i2c_drive.h"
#include "usb_descriptors.h"
#include "tusb.h"
#include "uart_rx_pio.h"

connection_status_t conn_stat = IDLE_CONNECTION;
output_control_t out_status = {0};
input_read_t in_status = {0};
channel_voltages_t adc_meas = {0};

repeat_timer_t led_timer = {0};
repeat_timer_t adc_tlm_timer = {0};
repeat_timer_ex_t adc_timer = {0};

bool output_set_flag = 0;
bool read_ins_flag = 0;
bool set_dac_flag = 0;

uint16_t set_dac_1_value = 2047;
uint16_t set_dac_2_value = 2047;

mcp4725_t dac;
mcp4725_t dac_2;

volatile bool usb_active = false;


// Here runs core 1
void core1_entry() {
    // Only initialize the tlm timer so it doesn't start straight away
    adc_tlm_timer.interval_ms = 1000;
    adc_tlm_timer.callback = transmit_adc_meas;
    adc_tlm_timer.next_time = make_timeout_time_ms(1000);
    adc_tlm_timer.initialized = true;
    adc_tlm_timer.enabled = false;
    
    mcp4725_fill(&dac, I2C_PORT, MCP4725_ADDR_DEFAULT);
    mcp4725_init(&dac);
    mcp4725_fill(&dac_2, I2C_PORT, MCP4725_ADDR_SECOND);
    mcp4725_init(&dac_2);

    int res = mcp4725_write_fast(&dac, 1595);
    if (res == PICO_ERROR_GENERIC)
    {
        sleep_ms(100);
    }

    uint16_t dac_val, eeprom_val;
    bool ready;
    mcp4725_read(&dac, &dac_val, &eeprom_val, &ready);

    while (1){

        if(output_set_flag == true) update_outputs();
        if(read_ins_flag == true) read_input_channels(&in_status);
        repeat_every_ex(&adc_timer, 100, read_adc_channels_wrapper, &adc_meas);
        if(conn_stat == COM_CONNECTED){
            repeat_every(&adc_tlm_timer, 1000, transmit_adc_meas);
        } 
        if (set_dac_flag == true){
            mcp4725_write_fast (&dac, set_dac_1_value);
            mcp4725_write_fast (&dac_2, set_dac_2_value);
            set_dac_flag = false;
        }
        tight_loop_contents();
        // sleep_ms(100);
    }  
}

// Here runs core 0
int main() {
    pico_led_init();
    init_inputs();
    init_outputs();
    adc_init_internal();
    tusb_init();
    serial_init();
    pio_uart_init_all(PIO_UART_BAUD_DEFAULT);
    aggregator_init();

    multicore_launch_core1(core1_entry);

    while (true) {

        process_rx_dma();

        handle_uart_rcv();

        pio_uart_tx_update();

        repeat_every(&led_timer, 1000, toggle_led);

        tud_task();

        feed_usb_rx();

        aggregator_update();
        transmit_pio_uart_channels();

        tight_loop_contents();
    }
}

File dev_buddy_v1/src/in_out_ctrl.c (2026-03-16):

#include "in_out_ctrl.h"
#include "hardware/adc.h"
#include "uart_coms.h"
#include "i2c_drive.h"
void toggle_led()
{
    static bool led_status = 0;
    if (led_status == true){
        pico_set_led(false);
        led_status = false;
    }
    else if (led_status == false){
        pico_set_led(true);
        led_status = true;
    }
}

void pico_led_init(void)
{
    gpio_init(PICO_DEFAULT_LED_PIN);
    gpio_set_dir(PICO_DEFAULT_LED_PIN, GPIO_OUT);
}

// Turn the LED on or off
void pico_set_led(bool led_on)
{
    // Just set the GPIO on or off
    gpio_put(PICO_DEFAULT_LED_PIN, led_on);
}

void update_outputs()
{
    gpio_put((uint)CHANNEL_OUT_0, out_status.channel_0_out);
    gpio_put((uint)CHANNEL_OUT_1, out_status.channel_1_out);
    gpio_put((uint)CHANNEL_OUT_2, out_status.channel_2_out);
#ifdef OUTPUTS_READY
    gpio_put((uint)CHANNEL_OUT_0, out_status.channel_0_out);
    gpio_put((uint)CHANNEL_OUT_1, out_status.channel_1_out);
    gpio_put((uint)CHANNEL_OUT_2, out_status.channel_2_out);
    gpio_put((uint)CHANNEL_OUT_3, out_status.channel_3_out);
    gpio_put((uint)CHANNEL_OUT_4, out_status.channel_4_out);
    gpio_put((uint)CHANNEL_OUT_5, out_status.channel_5_out);
    gpio_put((uint)CHANNEL_OUT_6, out_status.channel_6_out);
    gpio_put((uint)CHANNEL_OUT_7, out_status.channel_7_out);
    gpio_put((uint)CHANNEL_OUT_8, out_status.channel_8_out);
    gpio_put((uint)CHANNEL_OUT_9, out_status.channel_9_out);
    gpio_put((uint)CHANNEL_OUT_10, out_status.channel_10_out);
#endif

    output_set_flag = false;
}

void init_outputs()
{
    gpio_init((uint)CHANNEL_OUT_0);
    gpio_set_dir((uint)CHANNEL_OUT_0, GPIO_OUT);
    gpio_init((uint)CHANNEL_OUT_1);
    gpio_set_dir((uint)CHANNEL_OUT_1, GPIO_OUT);
    gpio_init((uint)CHANNEL_OUT_2);
    gpio_set_dir((uint)CHANNEL_OUT_2, GPIO_OUT);
#ifdef OUTPUTS_READY   
    gpio_init((uint)CHANNEL_OUT_0);
    gpio_set_dir((uint)CHANNEL_OUT_0, GPIO_OUT);
    gpio_init((uint)CHANNEL_OUT_1);
    gpio_set_dir((uint)CHANNEL_OUT_1, GPIO_OUT);
    gpio_init((uint)CHANNEL_OUT_2);
    gpio_set_dir((uint)CHANNEL_OUT_2, GPIO_OUT);
    gpio_init((uint)CHANNEL_OUT_3);
    gpio_set_dir((uint)CHANNEL_OUT_3, GPIO_OUT);
    gpio_init((uint)CHANNEL_OUT_4);
    gpio_set_dir((uint)CHANNEL_OUT_4, GPIO_OUT);
    gpio_init((uint)CHANNEL_OUT_5);
    gpio_set_dir((uint)CHANNEL_OUT_5, GPIO_OUT);
    gpio_init((uint)CHANNEL_OUT_6);
    gpio_set_dir((uint)CHANNEL_OUT_6, GPIO_OUT);
    gpio_init((uint)CHANNEL_OUT_7);
    gpio_set_dir((uint)CHANNEL_OUT_7, GPIO_OUT);
    gpio_init((uint)CHANNEL_OUT_8);
    gpio_set_dir((uint)CHANNEL_OUT_8, GPIO_OUT);
    gpio_init((uint)CHANNEL_OUT_9);
    gpio_set_dir((uint)CHANNEL_OUT_9, GPIO_OUT);
    gpio_init((uint)CHANNEL_OUT_10);
    gpio_set_dir((uint)CHANNEL_OUT_10, GPIO_OUT);
#endif
    gpio_init((uint)MUX_S0_PIN);
    gpio_set_dir((uint)MUX_S0_PIN, GPIO_OUT);
    gpio_init((uint)MUX_S1_PIN);
    gpio_set_dir((uint)MUX_S1_PIN, GPIO_OUT);
    gpio_init((uint)MUX_S2_PIN);
    gpio_set_dir((uint)MUX_S2_PIN, GPIO_OUT);
}
void init_inputs()
{
#ifdef OUTPUTS_READY   
    gpio_init((uint)CHANNEL_READ_0);
    gpio_set_dir((uint)CHANNEL_READ_0, GPIO_IN);
    gpio_pull_down((uint)CHANNEL_READ_0);
    gpio_init((uint)CHANNEL_READ_1);
    gpio_set_dir((uint)CHANNEL_READ_1, GPIO_IN);
    gpio_pull_down((uint)CHANNEL_READ_1);
    gpio_init((uint)CHANNEL_READ_2);
    gpio_set_dir((uint)CHANNEL_READ_2, GPIO_IN);
    gpio_pull_down((uint)CHANNEL_READ_2);
    gpio_init((uint)CHANNEL_READ_3);
    gpio_set_dir((uint)CHANNEL_READ_3, GPIO_IN);
    gpio_pull_down((uint)CHANNEL_READ_3);
    gpio_init((uint)CHANNEL_READ_4);
    gpio_set_dir((uint)CHANNEL_READ_4, GPIO_IN);
    gpio_pull_down((uint)CHANNEL_READ_4);
    gpio_init((uint)CHANNEL_READ_5);
    gpio_set_dir((uint)CHANNEL_READ_5, GPIO_IN);
    gpio_pull_down((uint)CHANNEL_READ_5);
    gpio_init((uint)CHANNEL_READ_6);
    gpio_set_dir((uint)CHANNEL_READ_6, GPIO_IN);
    gpio_pull_down((uint)CHANNEL_READ_6);
    gpio_init((uint)CHANNEL_READ_7);
    gpio_set_dir((uint)CHANNEL_READ_7, GPIO_IN);
    gpio_pull_down((uint)CHANNEL_READ_7);
    gpio_init((uint)CHANNEL_READ_8);
    gpio_set_dir((uint)CHANNEL_READ_8, GPIO_IN);
    gpio_pull_down((uint)CHANNEL_READ_8);
    gpio_init((uint)CHANNEL_READ_9);
    gpio_set_dir((uint)CHANNEL_READ_9, GPIO_IN);
    gpio_pull_down((uint)CHANNEL_READ_9);
    gpio_init((uint)CHANNEL_READ_10);
    gpio_set_dir((uint)CHANNEL_READ_10, GPIO_IN);
    gpio_pull_down((uint)CHANNEL_READ_10);
#endif
}

void read_input_channels (input_read_t *packet)
{
#ifdef OUTPUTS_READY
    packet->channel_0_in = gpio_get((uint)CHANNEL_READ_0);
    packet->channel_0_in = gpio_get((uint)CHANNEL_READ_1);
    packet->channel_0_in = gpio_get((uint)CHANNEL_READ_2);
    packet->channel_0_in = gpio_get((uint)CHANNEL_READ_3);
    packet->channel_0_in = gpio_get((uint)CHANNEL_READ_4);
    packet->channel_0_in = gpio_get((uint)CHANNEL_READ_5);
    packet->channel_0_in = gpio_get((uint)CHANNEL_READ_6);
    packet->channel_0_in = gpio_get((uint)CHANNEL_READ_7);
    packet->channel_0_in = gpio_get((uint)CHANNEL_READ_8);
    packet->channel_0_in = gpio_get((uint)CHANNEL_READ_9);
    packet->channel_0_in = gpio_get((uint)CHANNEL_READ_10);
#else
    packet->channel_0_in = 1;
    packet->channel_1_in = 0;
    packet->channel_2_in = 1;
    packet->channel_3_in = 0;
    packet->channel_4_in = 1;
    packet->channel_5_in = 0;
    packet->channel_6_in = 1;
    packet->channel_7_in = 0;
    packet->channel_8_in = 1;
    packet->channel_9_in = 0;
    packet->channel_10_in = 1;
#endif
    read_ins_flag = false;
}

void adc_init_internal ()
{
    adc_init();
    adc_gpio_init(V_CHANNELS_ADC_PIN);
    adc_gpio_init(I_CHANNELS_ADC_PIN);

}
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

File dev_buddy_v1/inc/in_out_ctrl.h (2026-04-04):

/** @file in_out_ctrl.h
 * 
 * @brief Global information used and visible by all files
 *
 * @par       
 * COPYRIGHT NOTICE: (c) TP Industries Group.  All rights reserved.
 */ 

#ifndef IN_OUT_CTRL
#define IN_OUT_CTRL

#include <stdint.h>
#include <stdio.h>
#include "pico/stdlib.h"
#include "globals.h"


// Digital output channels state
typedef struct __attribute__((packed))
{
    uint8_t channel_0_out;
    uint8_t channel_1_out;
    uint8_t channel_2_out;
    uint8_t channel_3_out;
    uint8_t channel_4_out;
    uint8_t channel_5_out;
    uint8_t channel_6_out;
    uint8_t channel_7_out;
    uint8_t channel_8_out;
    uint8_t channel_9_out;
    uint8_t channel_10_out;

} output_control_t;

// Digital input channels state
typedef struct __attribute__((packed))
{
    uint8_t channel_0_in;
    uint8_t channel_1_in;
    uint8_t channel_2_in;
    uint8_t channel_3_in;
    uint8_t channel_4_in;
    uint8_t channel_5_in;
    uint8_t channel_6_in;
    uint8_t channel_7_in;
    uint8_t channel_8_in;
    uint8_t channel_9_in;
    uint8_t channel_10_in;

} input_read_t;

// ADC measurements struct
typedef struct __attribute__((packed))
{
    float voltage_meas;
    float current_meas;

} channel_adc_meas_t;

// Voltage measurements for all channels
typedef struct __attribute__((packed))
{
    channel_adc_meas_t ch_adc_meas_0;
    channel_adc_meas_t ch_adc_meas_1;
    channel_adc_meas_t ch_adc_meas_2;
    channel_adc_meas_t ch_adc_meas_3;
    channel_adc_meas_t ch_adc_meas_4;
    channel_adc_meas_t ch_adc_meas_5;
    channel_adc_meas_t ch_adc_meas_6;
    channel_adc_meas_t ch_adc_meas_7;

} channel_voltages_t;

//TODO Have to put in here the actual pin numbers
// Digital Output channel pins
typedef enum {
    CHANNEL_OUT_0 = 13,
    CHANNEL_OUT_1 = 14,
    CHANNEL_OUT_2 = 15,
    CHANNEL_OUT_3,
    CHANNEL_OUT_4,
    CHANNEL_OUT_5,
    CHANNEL_OUT_6,
    CHANNEL_OUT_7,
    CHANNEL_OUT_8,
    CHANNEL_OUT_9,
    CHANNEL_OUT_10
} channel_pins_t;

// Digital Input channel pins
typedef enum {
    CHANNEL_READ_0 = 14,
    CHANNEL_READ_1 = 18,
    CHANNEL_READ_2 = 16,
    CHANNEL_READ_3,
    CHANNEL_READ_4,
    CHANNEL_READ_5,
    CHANNEL_READ_6,
    CHANNEL_READ_7,
    CHANNEL_READ_8,
    CHANNEL_READ_9,
    CHANNEL_READ_10
} in_channel_pins_t;

typedef enum {
    V_CHANNELS_ADC_PIN = 26,
    I_CHANNELS_ADC_PIN = 27
} adc_channel_pins_t;

// Multiplexer pins declarations
typedef enum {
    MUX_S0_PIN = 18,
    MUX_S1_PIN = 19,
    MUX_S2_PIN = 20
} mux_pins_t;

// Mux channel decrarations
typedef enum {
    MUX_CH0 = 0b000,  // S2=L S1=L S0=L -> Y0
    MUX_CH1 = 0b001,  // S2=L S1=L S0=H -> Y1
    MUX_CH2 = 0b010,  // S2=L S1=H S0=L -> Y2
    MUX_CH3 = 0b011,  // S2=L S1=H S0=H -> Y3
    MUX_CH4 = 0b100,  // S2=H S1=L S0=L -> Y4
    MUX_CH5 = 0b101,  // S2=H S1=L S0=H -> Y5
    MUX_CH6 = 0b110,  // S2=H S1=H S0=L -> Y6
    MUX_CH7 = 0b111,  // S2=H S1=H S0=H -> Y7
} mux_channel_t;

// Variables used inside main
extern output_control_t out_status;
extern input_read_t in_status;
extern channel_voltages_t adc_meas;
extern bool output_set_flag;
extern bool read_ins_flag;
extern uint16_t set_dac_1_value;
extern uint16_t set_dac_2_value;
// Function defines
void toggle_led();
void pico_led_init(void);
void pico_set_led(bool led_on);
void update_outputs();
void init_outputs();
void init_inputs();
void read_input_channels (input_read_t *packet);
void adc_init_internal ();
channel_voltages_t read_adc_channels ();
void read_adc_channels_wrapper(void *ctx);
void mux_select(mux_channel_t ch);

#endif

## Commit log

2026-02-28 Initial upload
    [DevBuddy.kicad_pcb, DevBuddy.kicad_sch]
2026-03-03 Hardware changes, ADC and start of power.
    [ADC_Channels.kicad_sch, DevBuddy.kicad_sch, INA190A2IDCKR.step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]
2026-03-04 Changes is hardware - Power
    [Power_Supply_1.kicad_sch]
2026-03-05 Added ADC functionality, APP and firm, App not stable.
2026-03-06 Added mux control, fixed adc tlm control, fixed app, added power in PCB
    [DevBuddy.kicad_sch, Power_Supply_1.kicad_sch, Power_Supply_2.kicad_sch]
2026-03-08 Changes in Variable buck - Hardware
    [DevBuddy.kicad_sch, Power_Supply_1.kicad_sch, Power_Supply_2.kicad_sch]
2026-03-08 Updated ReadMe with current info
2026-03-16 Added support for DACs in APP and device
2026-03-19 Added variable voltage channels/ PCB
    [DevBuddy.kicad_sch, Power_Supply_1.kicad_sch, Power_Supply_2.kicad_sch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]
2026-03-20 Heavy additions to schematic
    [2171820001.stp, ADC_Channels.kicad_sch, AOTA-B201610S3R3-101-T.stp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]
2026-04-02 Changed listing appearance of devices in app
2026-04-02 Finished USB bridge on device
2026-04-03 Added PIO uart channels support in device
2026-04-04 Finished PIO uart support RX&TX device & App
2026-04-05 Added uart comms in dispatcher
2026-04-27 More work into the PCB, mainly connectors
    [ADC_Channels.kicad_sch, Connectors.kicad_sch, DSG0008B.stp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]
2026-05-16 PCB, starting the board
    [ADC_Channels.kicad_sch, Connectors.kicad_sch, DevBuddy.kicad_pcb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]
2026-05-18 PCB, initial routing of submods
    [DevBuddy.kicad_pcb, Power_Supply_1.kicad_sch, TPS62913.stp]
2026-05-19 PCB, first draft of PCB layout
    [DevBuddy.kicad_pcb]
2026-05-21 PCB, Progress in routing.
    [10118194-0001LF.step, DevBuddy.kicad_pcb, DevBuddy_Logic.kicad_sch]
2026-05-26 PCB, Power routing nearly complete.
    [DevBuddy.kicad_pcb, DevBuddy_Logic.kicad_sch, Power_Supply_1.kicad_sch]
